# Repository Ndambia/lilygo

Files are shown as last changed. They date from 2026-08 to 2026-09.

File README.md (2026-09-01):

# LilyGo IoT Multi-Function PCB

A custom 4-layer KiCad PCB design integrating an ESP32 Wi-Fi/Bluetooth microcontroller with a SIM7600G-H 4G LTE Cat-4 cellular module, comprehensive power management, GPS tracking, GPRS connectivity, USB-C charging, LiPo battery management, environmental sensing, and USB-to-UART programming support.

---

## Table of Contents

- [Overview](#overview)
- [PCB Preview](#pcb-preview)
- [Schematic Overview](#schematic-overview)
- [Key Features](#key-features)
- [System Architecture](#system-architecture)
- [Schematic Sheets](#schematic-sheets)
- [Bill of Materials Summary](#bill-of-materials-summary)
- [Power System](#power-system)
- [Connectivity](#connectivity)
- [PCB Stackup & Design Rules](#pcb-stackup--design-rules)
- [Gerber & Manufacturing Files](#gerber--manufacturing-files)
- [Custom Libraries](#custom-libraries)
- [Datasheets](#datasheets)
- [Repository Structure](#repository-structure)
- [Getting Started](#getting-started)

---

## Overview

This project is a compact, feature-rich IoT development board built around the **ESP32-WROOM-32** and the **SIM7600G-H R2** 4G LTE module. It is designed for applications requiring cellular connectivity (4G/GPRS), GPS positioning, local Wi-Fi/Bluetooth, environmental sensing, and flexible power management from USB-C or a LiPo battery.

The board is designed in **KiCad** and targets JLCPCB / LCSC manufacturing and assembly (full BOM with LCSC part numbers included).

---

## PCB Preview

### Front Side (3D Render)

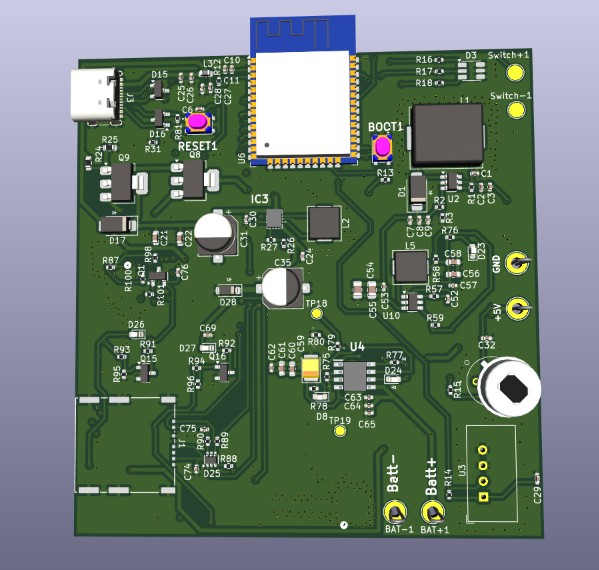
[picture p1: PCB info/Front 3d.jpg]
Front 3D Render


### Back Side (3D Render)

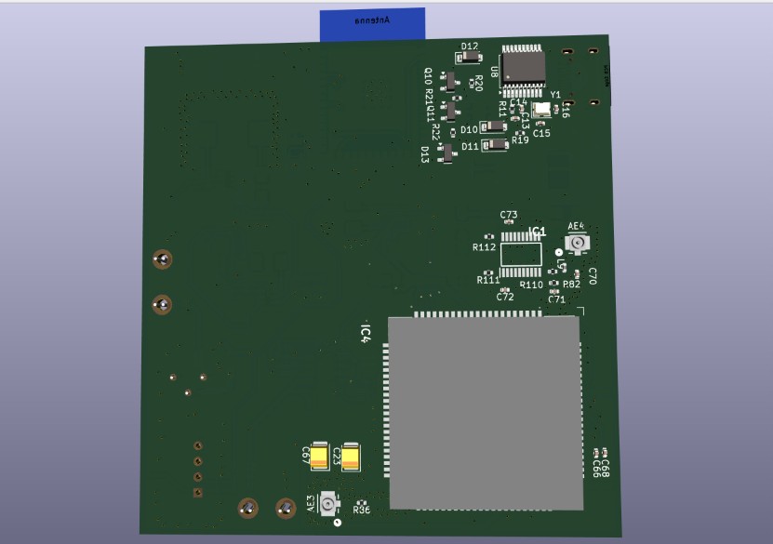
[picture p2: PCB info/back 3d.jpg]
Back 3D Render


### PCB Layout (Top View)

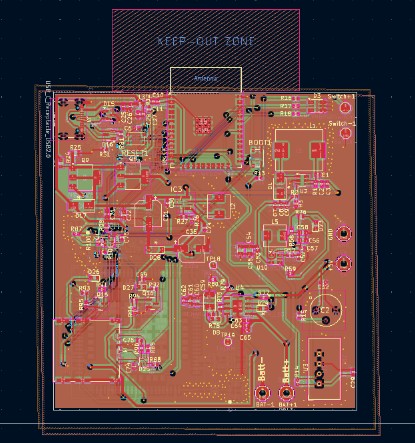
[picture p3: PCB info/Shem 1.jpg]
PCB Layout


---

## Schematic Overview

The full schematic (all sheets combined) is available as:

- 📄 [`PCB info/schematic.pdf`](PCB%20info/schematic.pdf) — Full combined schematic (all sheets)

Individual sheet PDFs:

| Sheet | Description | PDF |
|---|---|---|
| Root | Top-level schematic, ESP32, USB-UART, interfaces | *(see full schematic)* |
| BUCK\_CONVERTER\_3V3\_2A | 3.3 V / 2 A step-down (TPS56339DDCR) | [`schematic-BUCK_CONVERTER_3V3_2A_TPS56339DDCR.pdf`](PCB%20info/schematic-BUCK_CONVERTER_3V3_2A_TPS56339DDCR.pdf) |
| LIPO\_BAT\_CHARGER\_TP4056 | LiPo charger and protection circuit | [`schematic-LIPO_BAT_CHARGER_TP4056.pdf`](PCB%20info/schematic-LIPO_BAT_CHARGER_TP4056.pdf) |
| MT3608\_5V\_BOOST\_CONVERTOR | 5 V boost converter (MT3608) | [`schematic-MT3608_5V_BOOST_CONVERTOR.pdf`](PCB%20info/schematic-MT3608_5V_BOOST_CONVERTOR.pdf) |
| POWER\_PATH\_SELECTOR | Automatic USB/Battery power path switching | [`schematic-POWER_PATH_SELECTOR.pdf`](PCB%20info/schematic-POWER_PATH_SELECTOR.pdf) |
| SIM808\_GPRS\_GPS\_MODULE | SIM7600G-H R2 4G/GPS module and support circuitry | [`schematic-SIM808_GPRS_GPS_MODULE.pdf`](PCB%20info/schematic-SIM808_GPRS_GPS_MODULE.pdf) |

---

## Key Features

| Feature | Details |
|---|---|
| **MCU** | ESP32-WROOM-32D (Wi-Fi 802.11 b/g/n + Bluetooth 4.2 / BLE) |
| **Cellular** | SIM7600G-H R2 — 4G LTE Cat-4 / 3G / 2G, global bands |
| **GPS / GNSS** | Integrated via SIM7600G-H R2 (GPS + GLONASS) |
| **USB Interface** | USB-C receptacle (GCT USB4105), USB 2.0 |
| **USB-to-UART** | CH340T (SSOP-20) for ESP32 programming |
| **LiPo Charging** | TP4056 — up to 1 A charge rate, with protection |
| **3.3 V Rail** | TPS56339DDCR buck converter, 2 A output |
| **5 V Boost** | MT3608 step-up converter for 5 V peripherals |
| **Buck-Boost** | TPS630250RNCR — efficient intermediate rail |
| **Power Path** | Automatic USB / battery selector (NCE6005AR P-FETs) |
| **Environmental Sensor** | AM2302 (DHT22) — Temperature & Humidity |
| **PIR Sensor** | AS312 passive infrared motion detector |
| **SIM Card Slot** | GCT SIM7155-6-1-14-A nano/micro SIM connector |
| **GPS Antenna** | U.FL / IPEX connector (GT-RF1125A-01G) |
| **GPRS Antenna** | U.FL / IPEX connector (GT-RF1125A-01G) |
| **Level Shifting** | RS0108YQ20 8-channel bidirectional level shifter |
| **ESD Protection** | SP0502BAHT (USB lines), ESD0504F (multi-line) |
| **Reset / Boot** | Dedicated tactile push buttons (SKRPACE010) |
| **Status LEDs** | Power, Charging, Network status, RGB indicator |
| **Crystal** | 12 MHz SMD crystal (Y1) for CH340T |
| **PCB Layers** | 4-layer stackup (F.Cu / In1.Cu / In2.Cu / B.Cu) |
| **Board outline** | Edge cuts defined; antenna keep-out zone present |

---

## System Architecture

```
                          ┌──────────────────────────────────────────┐
                          │              USB-C (J3)                  │
                          │         GCT USB4105-GF-A                 │
                          └───────────────┬──────────────────────────┘
                                          │ VBUS (5V)
                          ┌───────────────▼──────────────────────────┐
                          │       Power Path Selector                │
                          │  NCE6005AR P-FET switches (Q8, Q9)       │
                          │  Auto USB / LiPo selection               │
                          └────────┬──────────────┬──────────────────┘
                                   │              │
                    ┌──────────────▼──┐    ┌──────▼──────────────────┐
                    │  TP4056 LiPo    │    │   MT3608 Boost (U2)     │
                    │  Charger (U4)   │    │   VBAT → 5 V            │
                    └──────────────┬──┘    └──────┬──────────────────┘
                                   │ VBAT         │ 5V rail
                    ┌──────────────▼──────────────▼──────────────────┐
                    │           TPS56339DDCR Buck (U10)              │
                    │              → 3.3 V / 2 A                     │
                    └──────────────┬──────────────────────────────────┘
                                   │ 3.3 V
                    ┌──────────────▼──────────────────────────────────┐
                    │         ESP32-WROOM-32D (U6)                   │
                    │    Wi-Fi / BLE / GPIO / UART / SPI / I2C       │
                    └──────┬──────────────┬──────────────────────────┘
                           │ UART         │ I2C / GPIO
          ┌────────────────▼──┐    ┌──────▼────────────────────────────┐
          │   CH340T (U8)     │    │   RS0108YQ20 Level Shifter (IC1)  │
          │   USB-UART Bridge │    │   3.3V ↔ 5V level translation     │
          └────────────────┬──┘    └──────┬────────────────────────────┘
                           │              │
                     USB-C (J3)    ┌──────▼──────────────────────────────┐
                  (programming)    │     SIM7600G-H R2 (IC4)             │
                                   │  4G LTE / 3G / 2G / GPS / GNSS     │
                                   │  GPS Antenna (AE4) + GPRS (AE3)    │
                                   │  SIM Card (J1 — SIM7155)           │
                                   └─────────────────────────────────────┘
                                   
          ┌────────────────────┐   ┌──────────────────┐
          │  AM2302 Sensor     │   │  AS312 PIR (IC2)  │
          │  Temp + Humidity   │   │  Motion Detection │
          └────────────────────┘   └──────────────────┘
```

---

## Schematic Sheets

The schematic is organized into hierarchical sheets:

### 1. Root Sheet
Top-level sheet containing:
- ESP32-WROOM-32D microcontroller and decoupling
- CH340T USB-to-UART bridge with 12 MHz crystal
- RS0108YQ20 bidirectional level shifter
- Reset and Boot buttons
- AM2302 temperature/humidity sensor
- AS312 PIR motion sensor
- Status LEDs (Power, Charging, Network, RGB)
- ESD protection diodes

### 2. BUCK_CONVERTER_3V3_2A_TPS56339DDCR
- Texas Instruments TPS56339DDCR synchronous buck regulator
- Input: up to ~5.5 V (battery or boosted USB)
- Output: 3.3 V @ 2 A for ESP32 and logic
- Teardrop-optimized copper pours

### 3. LIPO_BAT_CHARGER_TP4056
- TP4056 single-cell LiPo/Li-Ion charger IC
- Charge current configurable via R-prog resistor
- Charging indicator LED (D8 — Red) and Done indicator (D24 — Green)
- SS54 Schottky diode for reverse protection
- 4.2 V Zener clamp (D28) for overvoltage protection
- Large bulk capacitors (220 µF electrolytic on BAT+ rail)

### 4. MT3608_5V_BOOST_CONVERTOR
- MT3608 2 A boost converter (U2, SOT-23-6)
- Boosts VBAT (~3.7 V) to 5 V for USB and module power
- Inductor: 1 µH power bead (L2)
- SS54 freewheeling diode

### 5. POWER_PATH_SELECTOR
- Automatic switchover between USB VBUS and LiPo battery
- P-channel MOSFETs NCE6005AR (Q8, Q9) in back-to-back configuration
- Prevents battery discharge when USB is connected
- Handles reverse current blocking

### 6. SIM808_GPRS_GPS_MODULE (SIM7600G-H R2)
- SIM7600G-H R2 global-band 4G LTE Cat-4 module (IC4)
- GPS/GLONASS integrated receiver
- GPRS antenna connector AE3 (U.FL / IPEX)
- GPS antenna connector AE4 (U.FL / IPEX)
- SIM card connector J1 (GCT SIM7155-6-1-14-A)
- TPS630250RNCR buck-boost for module power rail
- Large 220 µF tantalum bulk capacitors for surge current

---

## Bill of Materials Summary

> Full BOM: [`Manufacturing files/BOM.csv`](Manufacturing%20files/BOM.csv)  
> Schematic netlist CSV: [`schematic.csv`](schematic.csv)

### ICs & Modules

| Ref | Part | Description |
|---|---|---|
| U6 | ESP32-WROOM-32D-N4 | Wi-Fi + BT MCU module |
| IC4 | SIM7600G-H R2 | 4G LTE / GPS module |
| U4 | TP4056 | LiPo battery charger |
| U10 | TPS56339DDCR | 3.3 V / 2 A buck regulator |
| U2 | MT3608 | 5 V boost converter |
| IC3 | TPS630250RNCR | Buck-boost regulator |
| IC1 | RS0108YQ20 | 8-ch bidirectional level shifter |
| IC2 | AS312 | PIR motion sensor |
| U8 | CH340T (SSOP-20) | USB-to-UART bridge |
| U3 | AM2302 | DHT22 temperature & humidity sensor |

### Connectors

| Ref | Part | Description |
|---|---|---|
| J3 | USB4105-GF-A | USB-C receptacle (USB 2.0) |
| J1 | SIM7155-6-1-14-A | SIM card connector |
| AE3 | GT-RF1125A-01G | GPRS / LTE antenna (U.FL) |
| AE4 | GT-RF1125A-01G | GPS antenna (U.FL) |

### Semiconductors & Passives (Key)

| Ref | Value/Part | Description |
|---|---|---|
| Q8, Q9 | NCE6005AR | P-channel power MOSFETs (power path) |
| Q15, Q16 | SI2302 | N-channel MOSFETs |
| Q10, Q11 | MMBT3904 | NPN signal transistors |
| Q1 | BC817 | NPN transistor |
| D1, D17 | SS54 | 5 A Schottky diodes |
| D10–D12 | B5819W | 1 A Schottky diodes |
| D13 | BAT54C | Dual Schottky (SOT-23) |
| D28 | BZT52C4V3 | 4.3 V Zener clamp |
| D3 | SMLVN6RGBFU1 | RGB LED |
| D15, D16 | SP0502BAHT | USB ESD protection |
| D25 | ESD0504F | Multi-line ESD protection |
| Y1 | 12 MHz | SMD crystal (2520 4-pin) for CH340T |
| L1 | 22 µH | Chilisin power inductor (buck) |
| L2 | 1 µH | Chilisin power inductor (boost) |
| L5 | 4.7 µH | Chilisin power inductor (buck-boost) |
| C31, C35 | 220 µF | Electrolytic bulk caps |
| C23, C67 | 220 µF | Tantalum bulk caps (cellular surge) |

Total unique component lines in BOM: **~82 line items**

---

## Power System

```
USB-C VBUS (5 V)
     │
     ├──► Power Path Selector (NCE6005AR)
     │         │
     │    ┌────┴──────────────────────────────────────────┐
     │    │ When USB present: powers system, charges LiPo │
     │    │ When no USB: LiPo powers system               │
     │    └────────────────────────────────────────────────┘
     │
     ├──► TP4056 LiPo Charger ──► LiPo Battery (BAT+ / BAT-)
     │
     └──► MT3608 Boost ──► 5 V internal rail
               │
               └──► TPS56339DDCR Buck ──► 3.3 V (ESP32, logic, peripherals)
                         │
                         └──► TPS630250RNCR Buck-Boost ──► SIM7600G-H power rail
```

| Rail | Regulator | Max Current | Load |
|---|---|---|---|
| 5 V boost | MT3608 | 2 A | Module VCC, USB |
| 3.3 V | TPS56339DDCR | 2 A | ESP32, logic ICs, sensors |
| Module VCC | TPS630250RNCR | — | SIM7600G-H R2 |
| VBAT | TP4056 output | 1 A charge | LiPo cell |

---

## Connectivity

| Interface | Notes |
|---|---|
| **4G LTE / GPRS** | SIM7600G-H R2, global bands, SMA/U.FL antenna |
| **GPS / GNSS** | Integrated in SIM7600G-H R2, dedicated U.FL antenna |
| **Wi-Fi** | ESP32 802.11 b/g/n (PCB trace antenna on module) |
| **Bluetooth** | ESP32 BT Classic 4.2 + BLE |
| **USB** | USB-C, USB 2.0, via CH340T UART bridge for programming |
| **Temperature/Humidity** | AM2302 (DHT22) single-wire protocol |
| **PIR Motion** | AS312 digital output |
| **SIM** | Nano/micro SIM via GCT connector |

---

## PCB Stackup & Design Rules

| Parameter | Value |
|---|---|
| **Layers** | 4 (F.Cu, In1.Cu, In2.Cu, B.Cu) |
| **Min track width** | 0.2 mm |
| **Min clearance** | 0.129 mm |
| **Min via diameter** | 0.6 mm |
| **Via drill** | 0.3 mm |
| **Min annular ring** | 0.15 mm |
| **Min hole-to-hole** | 0.25 mm |
| **Min copper-edge clearance** | 0.5 mm |
| **Solder mask clearance** | 0.005 mm |
| **Track widths used** | 0.19, 0.25, 0.3, 0.6 mm |
| **Teardrops** | Enabled on PTH pads, SMD pads, and vias |

> ⚠️ **Antenna Keep-Out Zone**: A copper-free keep-out zone is defined above the ESP32 module and near the cellular/GPS antenna connectors. Do not route traces or place copper fills in this area.

---

## Gerber & Manufacturing Files

### Gerber Files (`Gerber/`)

| File | Layer |
|---|---|
| `schematic-F_Cu.gbr` | Front copper |
| `schematic-B_Cu.gbr` | Back copper |
| `schematic-In1_Cu.gbr` | Inner layer 1 |
| `schematic-In2_Cu.gbr` | Inner layer 2 |
| `schematic-F_Mask.gbr` | Front solder mask |
| `schematic-B_Mask.gbr` | Back solder mask |
| `schematic-F_Paste.gbr` | Front solder paste |
| `schematic-B_Paste.gbr` | Back solder paste |
| `schematic-F_Silkscreen.gbr` | Front silkscreen |
| `schematic-B_Silkscreen.gbr` | Back silkscreen |
| `schematic-Edge_Cuts.gbr` | Board outline |
| `schematic-PTH.drl` | Plated through-hole drill file |
| `schematic-NPTH.drl` | Non-plated through-hole drill file |
| `schematic-job.gbrjob` | Gerber job file |

> 📦 Pre-zipped package: [`Gerber.zip`](Gerber.zip)

### Manufacturing Files (`Manufacturing files/`)

| File | Description |
|---|---|
| [`BOM.csv`](Manufacturing%20files/BOM.csv) | Full BOM with LCSC part numbers for JLCPCB SMT |
| [`Gerber.zip`](Manufacturing%20files/Gerber.zip) | Gerber archive for board fabrication |
| `placement/schematic-all-pos.csv` | Component placement / pick-and-place file |

---

## Custom Libraries (`lib/`)

Custom KiCad footprint and symbol libraries used in this project:

| Library | Part |
|---|---|
| `LIB_AM2302` | DHT22 / AM2302 temperature & humidity sensor |
| `LIB_AS312` | AS312 PIR motion sensor |
| `LIB_AXP2101` | AXP2101 power management IC |
| `LIB_RS0108YQ20` | RS0108YQ20 level shifter |
| `LIB_SIM7080G` | SIM7080G NB-IoT / Cat-M module |
| `LIB_SIM7600G-H_R2` | SIM7600G-H R2 4G module |
| `LIB_SKRPACE010` | SKRPACE010 tactile switch |
| `LIB_TP4056` | TP4056 LiPo charger |
| `LIB_TPS630250RNCR` | TPS630250RNCR buck-boost regulator |
| `Antenna conector` | U.FL / IPEX antenna connector |
| `SIM7155_6_1_14_A` | GCT SIM card connector |

---

## Datasheets (`Datasheet/`)

| Document | Description |
|---|---|
| [`AXP2101.pdf`](Datasheet/AXP2101.pdf) | AXP2101 PMIC datasheet |
| [`T-SIM7080G_Schematic.pdf`](Datasheet/T-SIM7080G_Schematic.pdf) | LilyGo T-SIM7080G reference schematic |
| [`TDM-2202_TDM-2205_ESP32-X7600X_schematic.pdf`](Datasheet/TDM-2202_TDM-2205_ESP32-X7600X_schematic.pdf) | ESP32 + SIM7600 reference design |
| [`sim7600 schematic.pdf`](Datasheet/sim7600%20schematic.pdf) | SIM7600 series module schematic reference |
| [`tps630250.pdf`](Datasheet/tps630250.pdf) | TPS630250 buck-boost regulator datasheet |

---

## Repository Structure

```
lilygo/
├── README.md                    ← This file
├── schematic.csv                ← Component netlist export
├── Gerber.zip                   ← Fabrication-ready Gerber archive
│
├── PCB info/                    ← Visual references
│   ├── Front 3d.jpg             ← 3D render — front
│   ├── back 3d.jpg              ← 3D render — back
│   ├── Shem 1.jpg               ← PCB layout screenshot
│   ├── schematic.pdf            ← Full combined schematic PDF
│   ├── schematic-BUCK_CONVERTER_3V3_2A_TPS56339DDCR.pdf
│   ├── schematic-LIPO_BAT_CHARGER_TP4056.pdf
│   ├── schematic-MT3608_5V_BOOST_CONVERTOR.pdf
│   ├── schematic-POWER_PATH_SELECTOR.pdf
│   └── schematic-SIM808_GPRS_GPS_MODULE.pdf
│
├── schematic/                   ← KiCad project files
│   ├── schematic.kicad_pro      ← KiCad project settings
│   ├── schematic.kicad_pcb      ← PCB layout file
│   ├── schematic.kicad_sch      ← Root schematic sheet
│   ├── BUCK_CONVERTER_3V3_2A_TPS56339DDCR.kicad_sch
│   ├── LIPO_BAT_CHARGER_TP4056.kicad_sch
│   ├── MT3608_5V_BOOST_CONVERTOR.kicad_sch
│   ├── POWER_PATH_SELECTOR.kicad_sch
│   └── SIM808_GPRS_GPSS_MODULE.kicad_sch
│
├── Gerber/                      ← Individual Gerber layer files
├── Manufacturing files/         ← JLCPCB production package
│   ├── BOM.csv                  ← BOM with LCSC part numbers
│   ├── Gerber.zip
│   └── placement/
│       └── schematic-all-pos.csv ← Pick-and-place file
│
├── lib/                         ← Custom KiCad libraries
│   ├── LIB_AM2302/
│   ├── LIB_AS312/
│   ├── LIB_SIM7600G-H_R2/
│   ├── LIB_TP4056/
│   ├── LIB_TPS630250RNCR/
│   └── ...
│
├── Datasheet/                   ← Reference datasheets
└── placement/                   ← Placement CSV (root-level copy)
```

---

## Getting Started

### Prerequisites

- [KiCad 7 or later](https://www.kicad.org/download/) (project was created with KiCad 7/8)
- LCSC / JLCPCB account for ordering

### Opening the Project

1. Clone or download this repository.
2. Open KiCad and select **File → Open Project**.
3. Navigate to `schematic/schematic.kicad_pro` and open it.
4. The schematic editor and PCB layout editor will be available from the KiCad project manager.

> **Note**: Ensure the `lib/` directory is accessible to KiCad for custom footprints and symbols. If prompted, add `lib/` as a project-level footprint library path in **Preferences → Manage Footprint Libraries**.

### Ordering the PCB (JLCPCB)

1. Upload [`Gerber.zip`](Gerber.zip) (or [`Manufacturing files/Gerber.zip`](Manufacturing%20files/Gerber.zip)) to [JLCPCB](https://jlcpcb.com).
2. Select **4-layer** stackup.
3. For SMT assembly, also upload:
   - [`Manufacturing files/BOM.csv`](Manufacturing%20files/BOM.csv)
   - [`Manufacturing files/placement/schematic-all-pos.csv`](Manufacturing%20files/placement/schematic-all-pos.csv)
4. Review component availability and substitutions as needed.

### Programming the ESP32

The board includes an on-board CH340T USB-to-UART bridge. To program:

1. Connect a USB-C cable to **J3**.
2. The CH340T will enumerate as a serial COM port.
3. Use the Arduino IDE, ESP-IDF, or PlatformIO targeting **ESP32-WROOM-32**.
4. Hold **BOOT** button while pressing **RESET** to enter download mode if needed.

---

*PCB designed in KiCad. Manufactured via JLCPCB. All LCSC part numbers included in BOM for one-stop sourcing.*

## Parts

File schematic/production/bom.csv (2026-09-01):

Designator | Footprint | Quantity | Value | LCSC Part #
+5V | TestPoint_Loop_D2.50mm_Drill1.85mm | 1 | 5v
AE3 | CONN_2337019-1_TEC | 1 | GPRS_ANTENNA | BWU.FL-IPEX1
AE4 | CONN_2337019-1_TEC | 1 | GPS_ANTENNA | BWU.FL-IPEX1
BAT+1 | TestPoint_Loop_D2.50mm_Drill1.85mm | 1 | BAT+
BAT-1 | TestPoint_Loop_D2.50mm_Drill1.85mm | 1 | BAT-
BOOT1, RESET1 | SMT_4.2X3.2_ | 2 | SW_Push
C1, C2, C30, C64, C65, C8, C9 | 0402 | 7 | 22u
C10, C68 | 0402 | 2 | 10u
C11, C6 | 0402 | 2 | 0.1u
C13 | 0402 | 1 | 22uF
C14, C52 | 0402 | 2 | 100nF
C15, C16 | 0402 | 2 | 22pF
C21 | 0603 | 1 | 4.7u
C22, C60 | 0603 | 2 | 10u
C23, C67 | CP_EIA-3528-21_Kemet-B | 2 | 220u | TLJB227M006R0500
C24, C27, C29, C3, C32, C62, C63, C66, C7, C72, C73, C74, C76 | 0402 | 13 | 100n
C25, C28 | 0402 | 2 | 4.7u
C26 | 0402 | 1 | 10n
C31, C35 | CP_Elec_6.3x5.4 | 2 | 220u | RVT1A221M0605
C53, C57 | 0402 | 2 | 100nF_65V
C54, C55 | 0805 | 2 | 10uF
C56, C58 | 0603 | 2 | 22uF
C59 | CP_EIA-3528-21_Kemet-B | 1 | 47u | TAJB476K010RNJ
C61 | 0603 | 1 | 100n
C69, C71 | 0402 | 2 | 33p
C70, C75 | 0402 | 2 | 22p
D1, D17 | D_SMA | 2 | SS54
D10, D11, D12 | D_SOD-123 | 3 | B5819W
D13 | SOT-23 | 1 | BAT54C
D15, D16 | SOT-23 | 2 | SP0502BAHT
D23 | 0603 | 1 | PWR
D24 | 0603 | 1 | DONE_GRN_LED
D25 | SOT-363_SC-70-6 | 1 | ESD0504F | ESD0504F
D26 | 0603 | 1 | LED_net
D27 | 0603 | 1 | LED_status
D28 | D_SOD-123 | 1 | 4.2v Zener
D3 | LED_ROHM_SMLVN6 | 1 | SMLVN6RGB
D8 | 0603 | 1 | CHARGING_RED_LED
GND | TestPoint_Loop_D2.50mm_Drill1.85mm | 1 | GND
IC1 | SOP65P640X120-20N | 1 | RS0108YQ20
IC2 | AS312 | 1 | AS312
IC3 | TPS630250RNCR | 1 | TPS630250RNCR
IC4 | SIM7600GHR2 | 1 | SIM7600G-H_R2
J1 | SIM7155-6-1-14-A_GCT | 1 | SIM7155-6-1-14-A
J3 | USB_C_Receptacle_GCT_USB4105-xx-A_16P_TopMnt_Horizontal | 1 | USB_C_Receptacle_USB2.0
L1 | L_Chilisin_BMRG00101030 | 1 | 22uH | CYA1040-22UH
L2 | L_Chilisin_BMRx00050512-B | 1 | 1uH | YSPI0530S-1R0M
L3 | 0603 | 1 | 2A_bead
L5 | L_Chilisin_BMRx00050512-B | 1 | 4.7uH | YSPI0530S-4R7M
L9 | 0402 | 1 | 47nH
Q1 | SOT-23 | 1 | BC817
Q10, Q11 | SOT-23 | 2 | MMBT3904
Q15, Q16 | SOT-23 | 2 | SI2302
Q8, Q9 | SOT-223-3_TabPin2 | 2 | NCE6005AR
R1, R11, R110, R12, R13, R19, R20, R21, R59, R95, R96 | 0402 | 11 | 10K
R100, R101, R14, R87, R98 | 0402 | 5 | 4.7k
R111, R112 | 0402 | 2 | 47k
R15, R16, R17, R18, R75, R76, R77, R78, R93, R94 | 0402 | 10 | 1k
R2 | 0402 | 1 | 120K
R22 | 0402 | 1 | 220R
R24 | 0603 | 1 | 1K
R25 | 0603 | 1 | 10K
R26 | 0402 | 1 | 720K
R27 | 0402 | 1 | 180K
R3 | 0402 | 1 | 16K
R31, R81 | 0402 | 2 | 5.1K
R57 | 0402 | 1 | 30R
R58 | 0402 | 1 | 30.9K
R79 | 0402 | 1 | 4870
R80 | 0402 | 1 | 86600
R82 | 0402 | 1 | 47R
R86 | 0402 | 1 | 0R
R88, R89, R90 | 0402 | 3 | 22R
R91, R92 | 0402 | 2 | 390R
SWITCH+1 | TestPoint_Pad_D2.5mm | 1 | Switch+
SWITCH-1 | TestPoint_Pad_D2.5mm | 1 | Switch-
TP18 | TestPoint_Pad_D1.5mm | 1 | THERM+
TP19 | TestPoint_Pad_D1.5mm | 1 | THERM-
U10 | SOT-23-6 | 1 | TPS56339DDC
U2 | SOT-23-6 | 1 | MT3608
U3 | ASAIR_AM2302_P2.54mm_Vertical | 1 | AM2302
U4 | SOIC127P600X175-9N | 1 | TP4056
U6 | ESP32-WROOM-32 | 1 | ESP32-WROOM-32
U8 | SSOP-20_5.3x7.2mm_P0.65mm | 1 | CH340T(SSOP20W)
Y1 | Crystal_SMD_2520-4Pin_2.5x2.0mm | 1 | 12MHz

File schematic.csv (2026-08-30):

Comment | Designator | Footprint | Quantity
4.7u | C21 | C_0603_1608Metric | 1
16K | R3 | R_0402_1005Metric | 1
SP0502BAHT | D15,D16 | SOT-23 | 2
LED_net | D26 | LED_0603_1608Metric | 1
SW_Push | RESET1,BOOT1 | SMT_4.2X3.2_ | 2
1K | R94,R78,R76,R77,R93,R75 | R_0402_1005Metric | 6
33p | C69,C71 | C_0402_1005Metric | 2
10n | C26 | C_0402_1005Metric_Pad0.74x0.62mm_HandSolder | 1
1K | R24 | R_0603_1608Metric | 1
100n | C24,C74,C76,C3,C62,C63,C7,C66,C72,C73 | C_0402_1005Metric | 10
22R | R89,R90,R88 | R_0402_1005Metric | 3
SIM7155-6-1-14-A | J1 | SIM7155-6-1-14-A_GCT | 1
4.7u | C28,C25 | C_0402_1005Metric_Pad0.74x0.62mm_HandSolder | 2
0.1u | C6,C11 | C_0402_1005Metric | 2
MT3608 | U2 | SOT-23-6 | 1
22u | C65,C9,C8,C1,C64,C2,C30 | C_0402_1005Metric | 7
PWR | D23 | LED_0603_1608Metric | 1
10K | R25 | R_0603_1608Metric | 1
2A_bead | L3 | L_0603_1608Metric | 1
30.9K | R58 | R_0402_1005Metric | 1
100nF | C52,C14 | C_0402_1005Metric | 2
4.7k | R98,R87,R14,R100,R101 | R_0402_1005Metric | 5
LED_status | D27 | LED_0603_1608Metric | 1
10K | R59,R1,R95,R96 | R_0402_1005Metric | 4
390R | R92,R91 | R_0402_1005Metric | 2
10k | R13,R12,R11,R20,R19,R21,R110 | R_0402_1005Metric | 7
1uH | L2 | L_Chilisin_BMRx00050512-B | 1
SS54 | D17,D1 | D_SMA | 2
22uF | C58,C56 | C_0603_1608Metric | 2
10u | C10,C68 | C_0402_1005Metric | 2
120K | R2 | R_0402_1005Metric | 1
10uF | C55,C54 | C_0805_2012Metric | 2
86600 | R80 | R_0402_1005Metric | 1
SMLVN6RGB | D3 | LED_ROHM_SMLVN6 | 1
100n | C61 | C_0603_1608Metric | 1
720K | R26 | R_0402_1005Metric | 1
ESD0504F | D25 | SOT-363_SC-70-6 | 1
220u | C35,C31 | CP_Elec_6.3x5.4 | 2
AS312 | IC2 | AS312 | 1
10u | C22,C60 | C_0603_1608Metric | 2
SI2302 | Q16,Q15 | SOT-23 | 2
DONE_GRN_LED | D24 | LED_0603_1608Metric | 1
100nF_65V | C53,C57 | C_0402_1005Metric | 2
NCE6005AR | Q9,Q8 | SOT-223-3_TabPin2 | 2
22p | C75,C70 | C_0402_1005Metric | 2
TPS56339DDC | U10 | SOT-23-6 | 1
100n | C32,C29,C27 | C_0402_1005Metric_Pad0.74x0.62mm_HandSolder | 3
5.1K | R31,R81 | R_0402_1005Metric | 2
22uH | L1 | L_Chilisin_BMRG00101030 | 1
47u | C59 | CP_EIA-3528-21_Kemet-B | 1
1k | R17,R18,R15,R16 | R_0402_1005Metric | 4
4870 | R79 | R_0402_1005Metric | 1
180K | R27 | R_0402_1005Metric | 1
AM2302 | U3 | ASAIR_AM2302_P2.54mm_Vertical | 1
USB_C_Receptacle_USB2.0 | J3 | USB_C_Receptacle_GCT_USB4105-xx-A_16P_TopMnt_Horizontal | 1
4.7uH | L5 | L_Chilisin_BMRx00050512-B | 1
4.2v Zener | D28 | D_SOD-123 | 1
TP4056 | U4 | SOIC127P600X175-9N | 1
30R | R57 | R_0402_1005Metric | 1
TPS630250RNCR | IC3 | TPS630250RNCR | 1
BC817 | Q1 | SOT-23 | 1
CHARGING_RED_LED | D8 | LED_0603_1608Metric | 1
ESP32-WROOM-32 | U6 | ESP32-WROOM-32 | 1
RS0108YQ20 | IC1 | SOP65P640X120-20N | 1
22pF | C15,C16 | C_0402_1005Metric | 2
BAT54C | D13 | SOT-23 | 1
47R | R82 | R_0402_1005Metric | 1
CH340T(SSOP20W) | U8 | SSOP-20_5.3x7.2mm_P0.65mm | 1
B5819W | D10,D12,D11 | D_SOD-123 | 3
MMBT3904 | Q11,Q10 | SOT-23 | 2
12MHz | Y1 | Crystal_SMD_2520-4Pin_2.5x2.0mm | 1
GPS_ANTENNA | AE4 | CONN_2337019-1_TEC | 1
220u | C23,C67 | CP_EIA-3528-21_Kemet-B | 2
47k | R112,R111 | R_0402_1005Metric | 2
47nH | L9 | L_0402_1005Metric | 1
GPRS_ANTENNA | AE3 | CONN_2337019-1_TEC | 1
0R | R86 | R_0402_1005Metric | 1
220R | R22 | R_0402_1005Metric | 1
SIM7600G-H_R2 | IC4 | SIM7600GHR2 | 1
22uF | C13 | C_0402_1005Metric | 1

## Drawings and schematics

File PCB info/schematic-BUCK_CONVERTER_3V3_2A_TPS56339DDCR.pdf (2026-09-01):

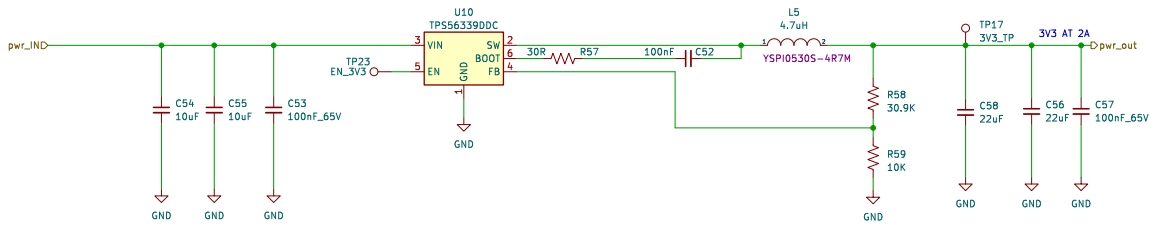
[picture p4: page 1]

1 SW 2 BOOT 6 FB 4 U10 TPS56339DDC GND

Id: 2/7 Title: File: BUCK_CONVERTER_3V3_2A_TPS56339DDCR.kicad_sch Sheet: /BUCK_CONVERTER_3V3_2A_TPS56339DDCR/

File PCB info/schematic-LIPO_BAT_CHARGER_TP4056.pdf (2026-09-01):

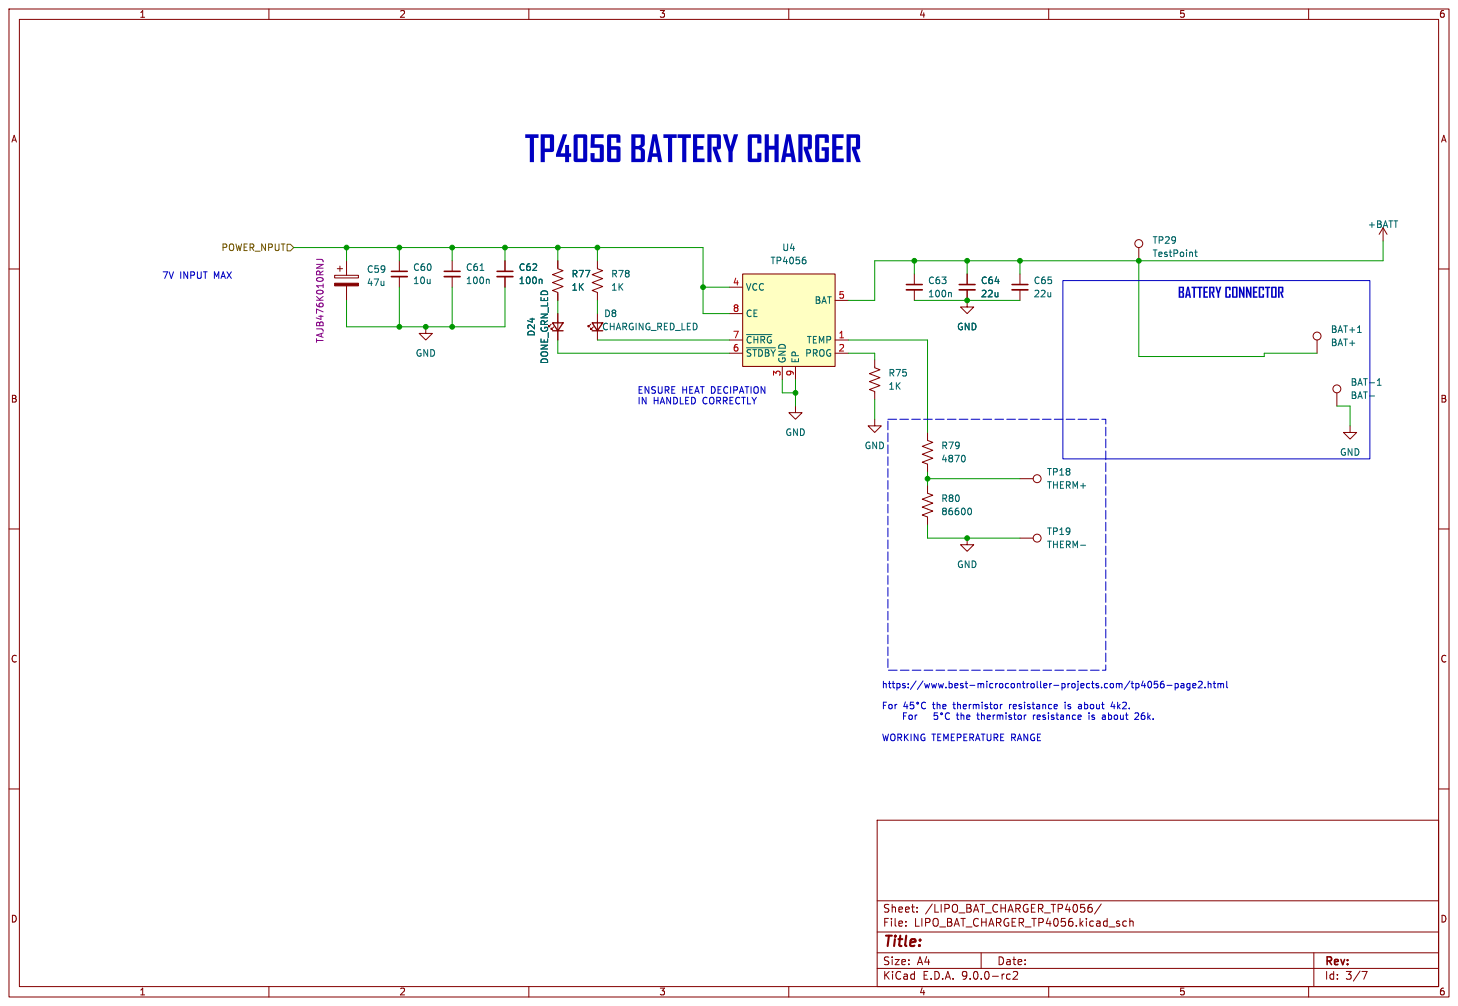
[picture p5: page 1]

BAT+1 BAT+BAT-1 BAT- GND

https://www.best-microcontroller-projects.com/tp4056-page2.html ENSURE HEAT DECIPATION

Id: 3/7 Title: File: LIPO_BAT_CHARGER_TP4056.kicad_sch Sheet: /LIPO_BAT_CHARGER_TP4056/

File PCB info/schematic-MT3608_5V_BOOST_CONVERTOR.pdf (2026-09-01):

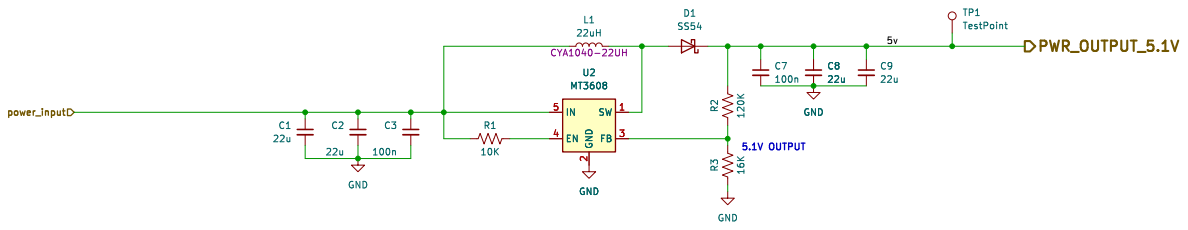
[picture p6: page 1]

Id: 6/7 Title: File: MT3608_5V_BOOST_CONVERTOR.kicad_sch Sheet: /MT3608_5V_BOOST_CONVERTOR/ C3

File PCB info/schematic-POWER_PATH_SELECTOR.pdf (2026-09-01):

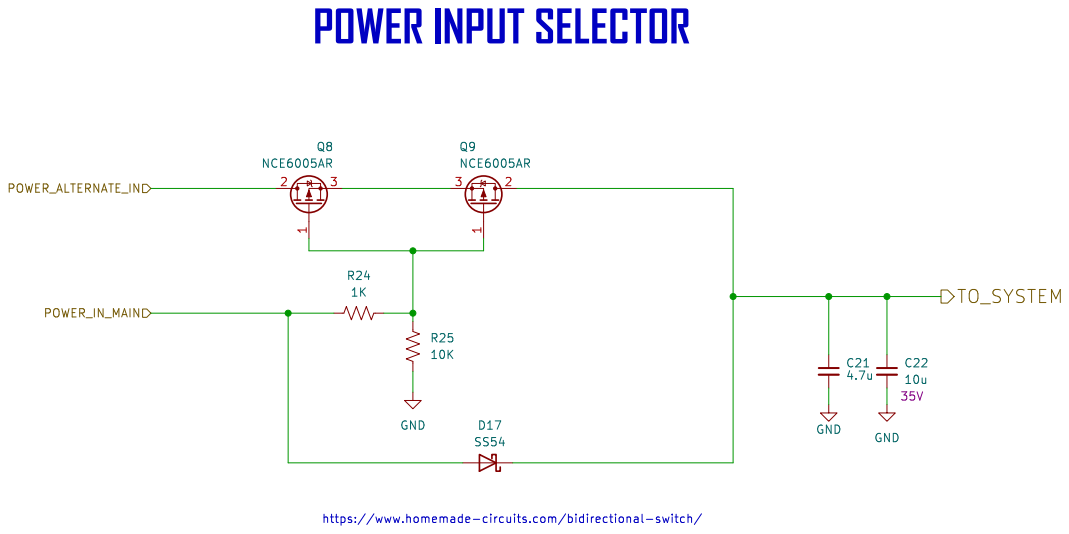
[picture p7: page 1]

Id: 5/7 Title: File: POWER_PATH_SELECTOR.kicad_sch Sheet: /POWER_PATH_SELECTOR/ GND

https://www.homemade-circuits.com/bidirectional-switch/

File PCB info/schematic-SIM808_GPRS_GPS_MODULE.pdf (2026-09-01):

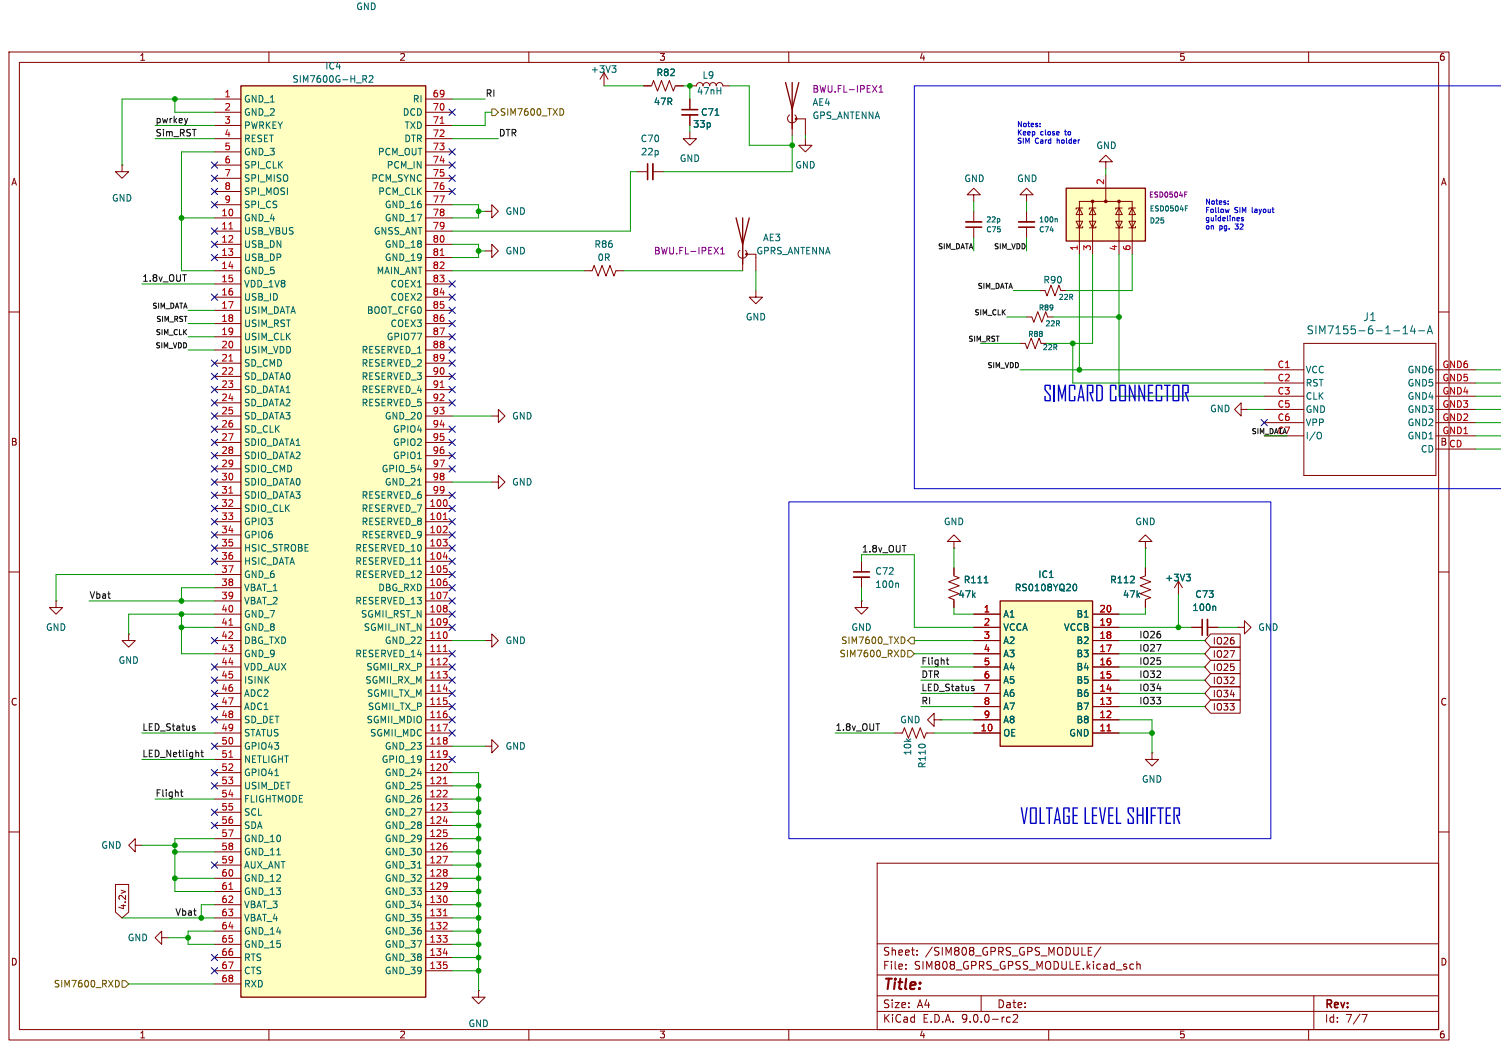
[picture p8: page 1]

STATUS LIGHT VOLTAGE LEVELSHIFTER

Notes: Keep close to SIM Card holder SIMCARD CONNECTOR

Id: 7/7 Title: File: SIM808_GPRS_GPSS_MODULE.kicad_sch Sheet: /SIM808_GPRS_GPS_MODULE/ GND

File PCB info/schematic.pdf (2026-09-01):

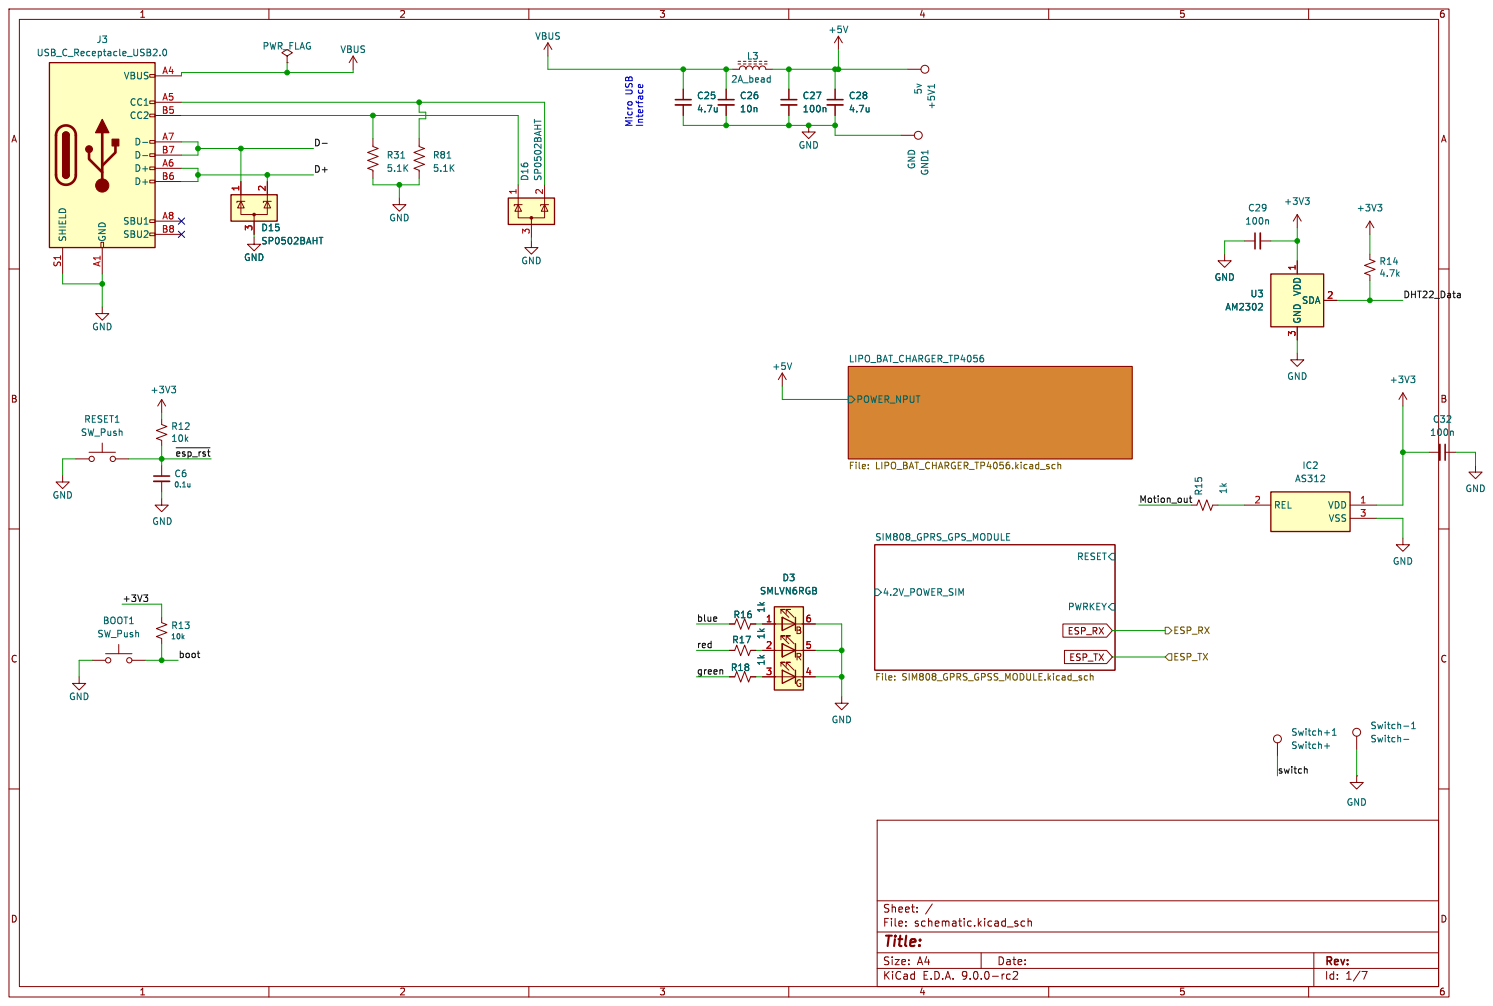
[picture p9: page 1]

3 SDA U3 2 AM2302 GND GND GND

Id: 1/7 Title: File: schematic.kicad_sch Sheet: /


1 SW 2 BOOT 6 FB 4 U10 TPS56339DDC GND

Id: 2/7 Title: File: BUCK_CONVERTER_3V3_2A_TPS56339DDCR.kicad_sch Sheet: /BUCK_CONVERTER_3V3_2A_TPS56339DDCR/


9 BAT 5 TEMP 1 PROG 2 U4 TP4056 GND

BAT+1 BAT+BAT-1 BAT- GND

https://www.best-microcontroller-projects.com/tp4056-page2.html ENSURE HEAT DECIPATION

Id: 3/7 Title: File: LIPO_BAT_CHARGER_TP4056.kicad_sch Sheet: /LIPO_BAT_CHARGER_TP4056/

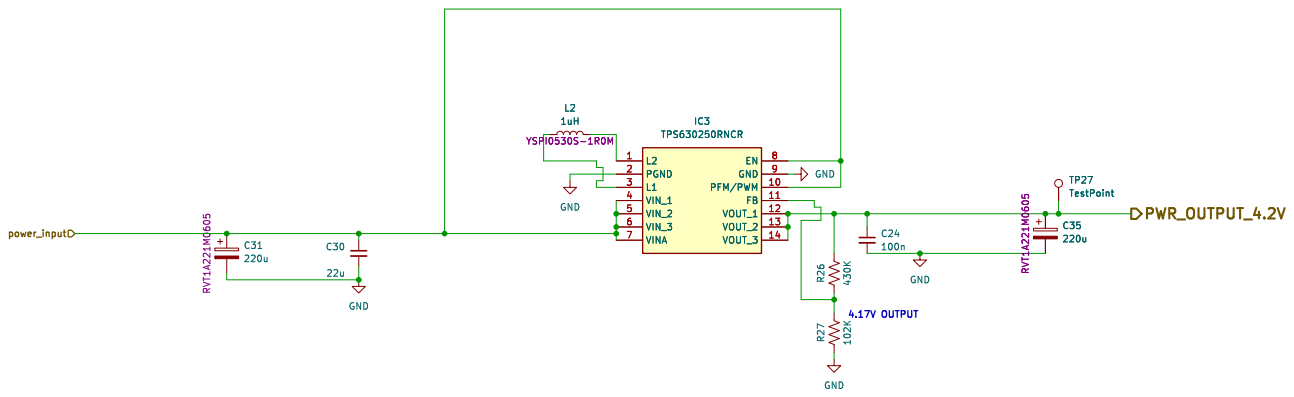
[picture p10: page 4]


Id: 5/7 Title: File: POWER_PATH_SELECTOR.kicad_sch Sheet: /POWER_PATH_SELECTOR/ GND

https://www.homemade-circuits.com/bidirectional-switch/


Id: 6/7 Title: File: MT3608_5V_BOOST_CONVERTOR.kicad_sch Sheet: /MT3608_5V_BOOST_CONVERTOR/ C3


STATUS LIGHT VOLTAGE LEVELSHIFTER

Notes: Keep close to SIM Card holder SIMCARD CONNECTOR

Id: 7/7 Title: File: SIM808_GPRS_GPSS_MODULE.kicad_sch Sheet: /SIM808_GPRS_GPS_MODULE/ GND

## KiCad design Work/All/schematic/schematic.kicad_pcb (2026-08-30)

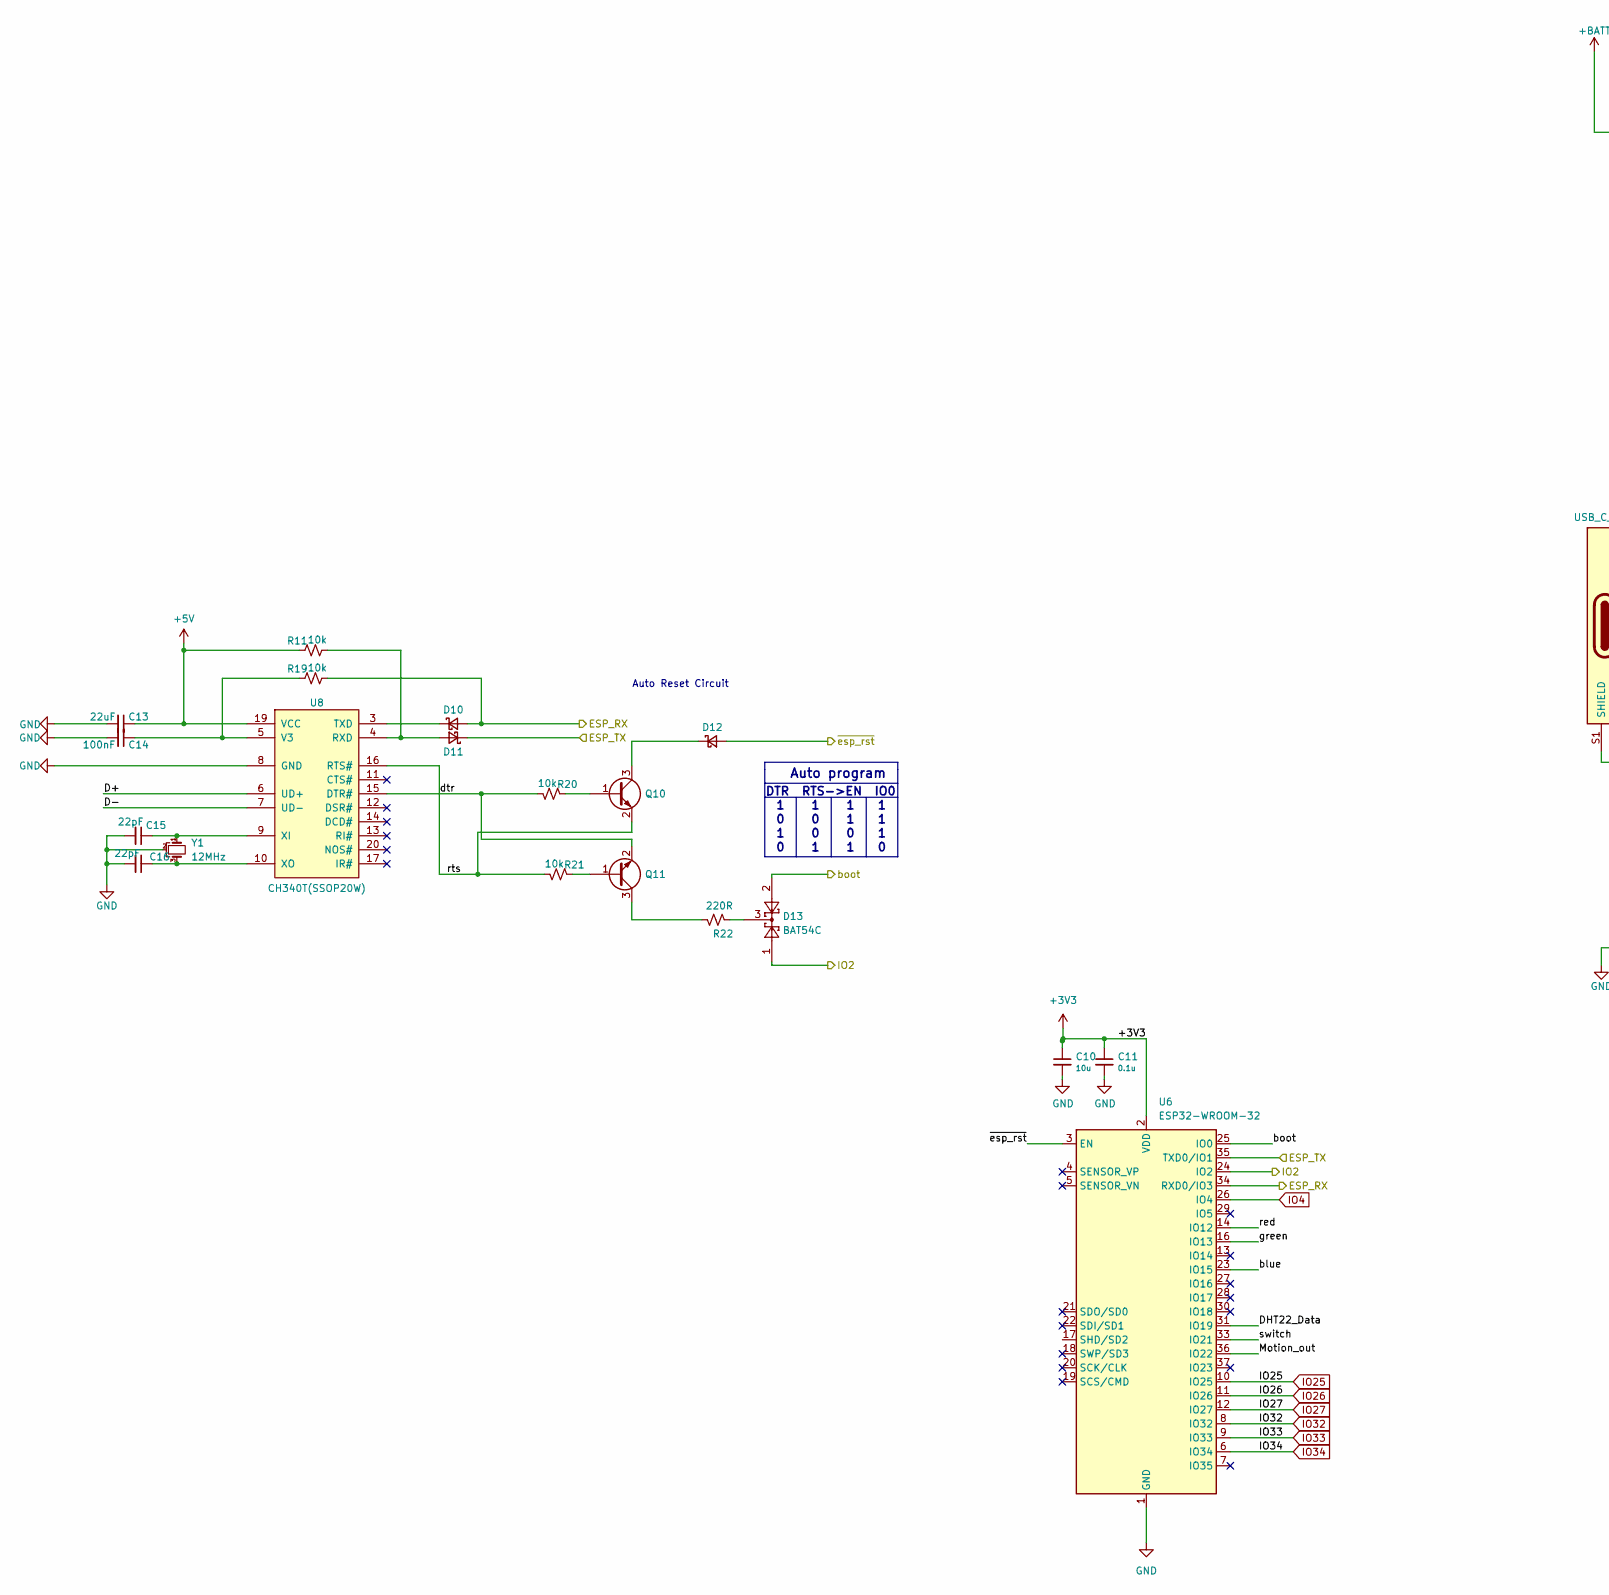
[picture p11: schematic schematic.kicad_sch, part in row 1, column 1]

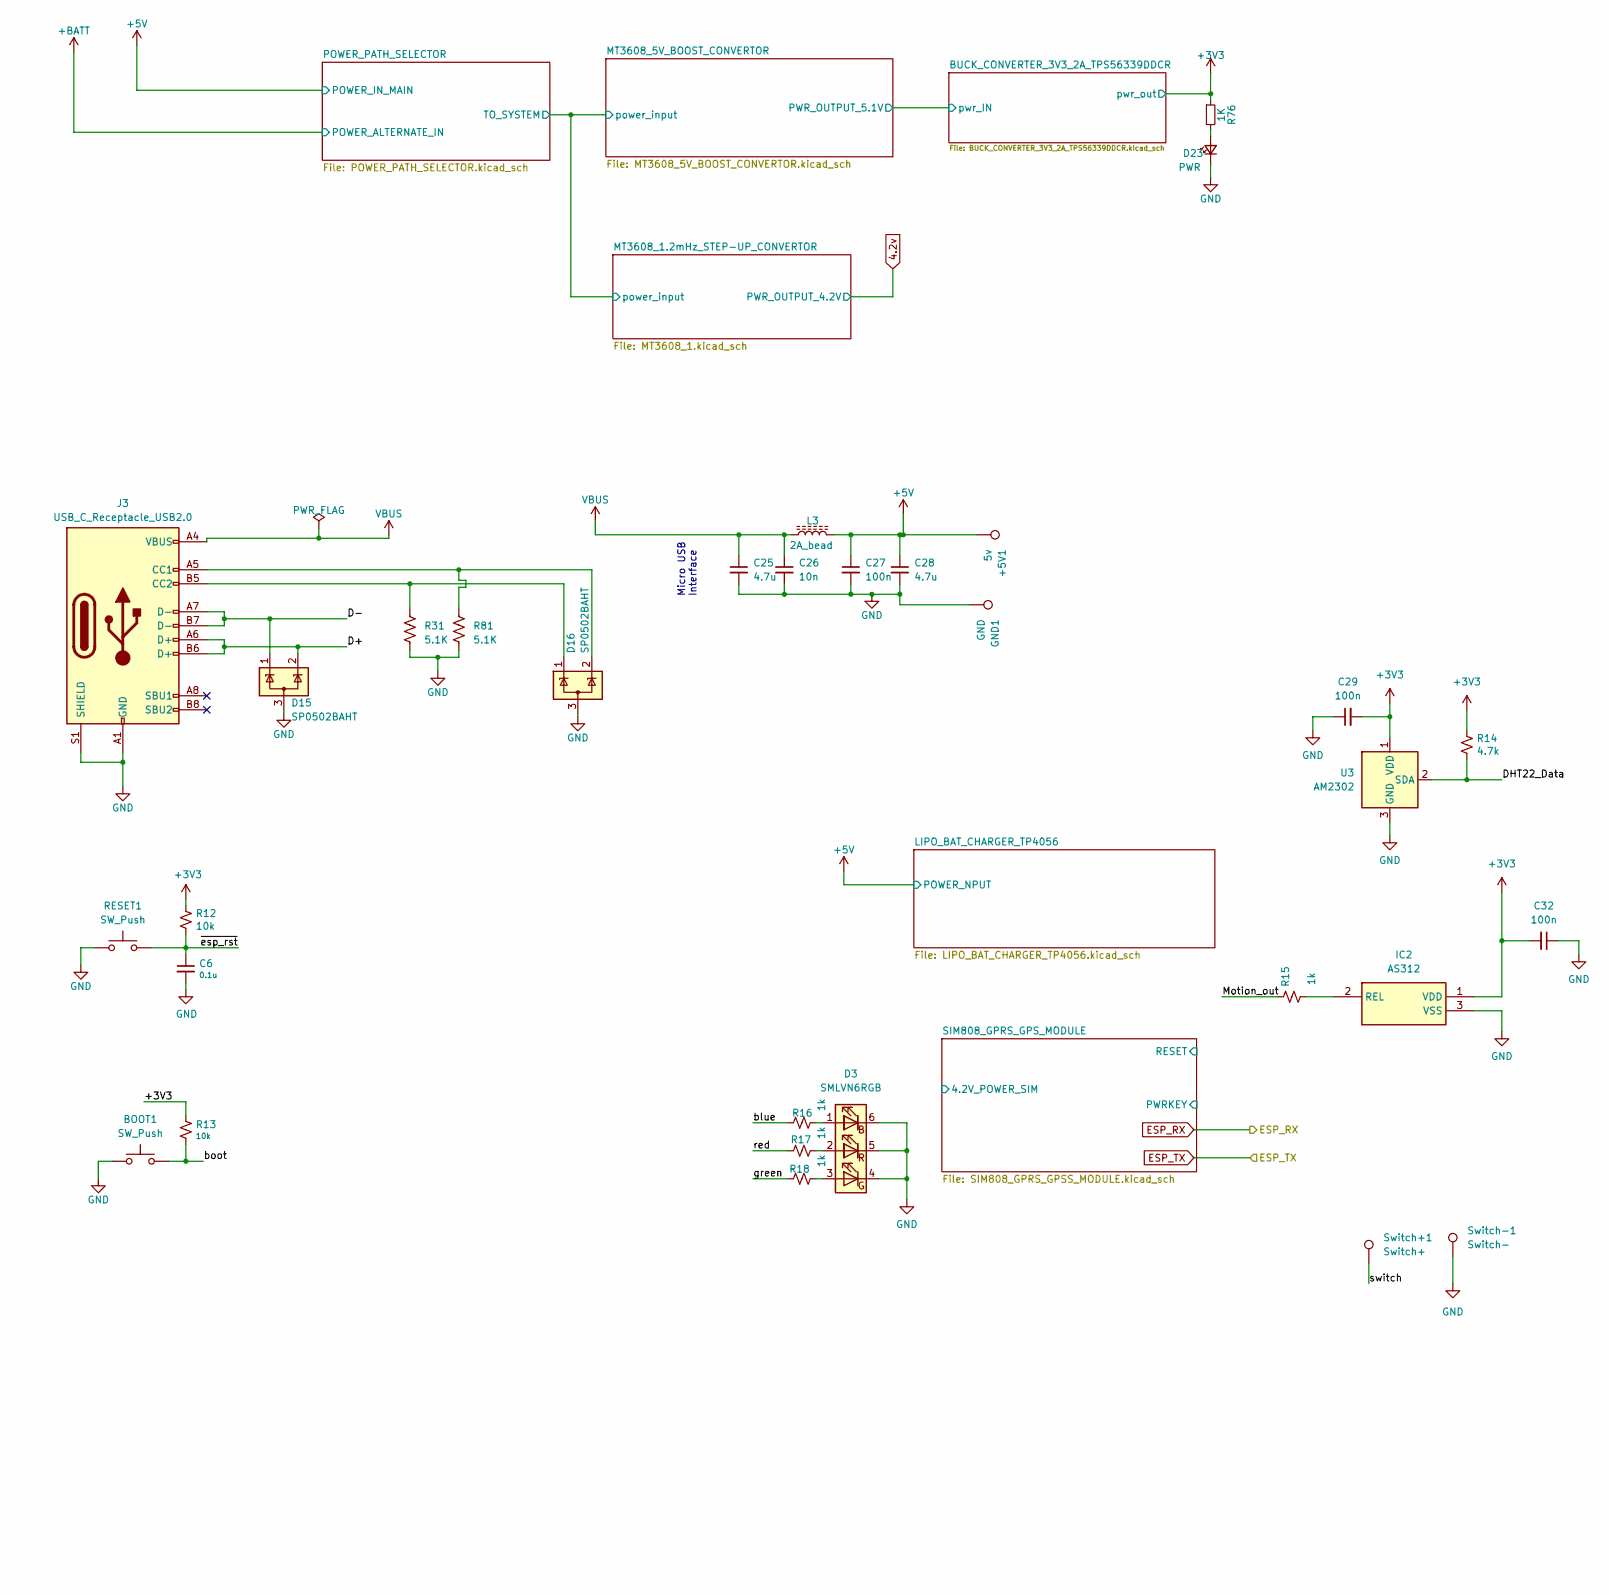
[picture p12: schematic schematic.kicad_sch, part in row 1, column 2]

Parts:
+5V1: 5v; TestPoint_Loop_D2.50mm_Drill1.85mm
BOOT1: SW_Push; SMT_4.2X3.2_
C6, C11: 0.1u; C_0402_1005Metric
C10: 10u; C_0402_1005Metric
C13: 22uF; C_0402_1005Metric
C14: 100nF; C_0402_1005Metric
C15, C16: 22pF; C_0402_1005Metric
C25, C28: 4.7u; C_0402_1005Metric_Pad0.74x0.62mm_HandSolder
C26: 10n; C_0402_1005Metric_Pad0.74x0.62mm_HandSolder
C27, C29, C32: 100n; C_0402_1005Metric_Pad0.74x0.62mm_HandSolder
D3: SMLVN6RGB; LED_ROHM_SMLVN6
D10, D11, D12: B5819W; D_SOD-123
D13: BAT54C; SOT-23
D15, D16: SP0502BAHT; SOT-23
D23: PWR; LED_0603_1608Metric
GND1: GND; TestPoint_Loop_D2.50mm_Drill1.85mm
IC2: AS312; Manufacturer_Part_Number AS312
J3: USB_C_Receptacle_USB2.0; USB_C_Receptacle_GCT_USB4105-xx-A_16P_TopMnt_Horizontal
L3: 2A_bead; L_0603_1608Metric
Q10, Q11: MMBT3904; SOT-23
R11, R12, R13, R19, R20, R21: 10k; R_0402_1005Metric
R14: 4.7k; R_0402_1005Metric
R15, R16, R17, R18: 1k; R_0402_1005Metric
R22: 220R; R_0402_1005Metric
R31, R81: 5.1K; R_0402_1005Metric
R76: 1K; R_0402_1005Metric
RESET1: SW_Push; SMT_4.2X3.2_
Switch+1: Switch+; TestPoint_Pad_D2.5mm
Switch-1: Switch-; TestPoint_Pad_D2.5mm
U3: AM2302; ASAIR_AM2302_P2.54mm_Vertical
U6: ESP32-WROOM-32
U8: CH340T(SSOP20W); SSOP-20_5.3x7.2mm_P0.65mm
Y1: 12MHz; Crystal_SMD_2520-4Pin_2.5x2.0mm

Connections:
+3V3: C10.1, C11.1, C29.2, C32.2, IC2.1 (VDD), R12.1, R13.1, R14.1, R76.1, U3.1 (VDD), U6.2 (VDD); also elsewhere on the board
+5V: +5V1.1, C13.1, C27.1, C28.1, L3.1, R11.1, U8.19 (VCC); also elsewhere on the board
/D+: D15.2 (K), J3.A6 (D+), J3.B6 (D+), U8.6 (UD+)
/D-: D15.1 (K), J3.A7 (D-), J3.B7 (D-), U8.7 (UD-)
/DHT22_Data: R14.2, U3.2 (SDA), U6.31 (IO19)
/IO2: D13.1, U6.24 (IO2)
/Motion_out: R15.1, U6.36 (IO22)
/blue: R16.1, U6.23 (IO15)
/boot: BOOT1.2, D13.2, R13.2, U6.25 (IO0)
/green: R18.1, U6.16 (IO13)
/red: R17.1, U6.14 (IO12)
/switch: Switch+1.1, U6.33 (IO21)
/~esp_rst: C6.1, D12.2 (A), R12.2, RESET1.2, U6.3 (EN)
ESP_RX: D10.2 (A), R19.2, U6.34 (RXD0/IO3)
ESP_TX: D11.1 (K), U6.35 (TXD0/IO1)
GND: BOOT1.1, C6.2, C10.2, C11.2, C13.2, C14.2, C15.2, C16.2, C25.2, C26.2, C27.2, C28.2, C29.1, C32.1, D3.4 (GK), D3.5 (RK), D3.6 (BK), D15.3 (A), D16.3 (A), D23.1 (K), GND1.1, IC2.3 (VSS), J3.A1 (GND), J3.A12 (GND), J3.B1 (GND), J3.B12 (GND), J3.S1 (SHIELD), R31.2, R81.2, RESET1.1, Switch-1.1, U3.3 (GND), U3.4 (GND), U6.1 (GND), U6.15 (GND), U6.38 (GND), U6.39 (GND), U8.8 (GND), Y1.2; also elsewhere on the board
IO4: U6.26 (IO4); also elsewhere on the board
IO25: U6.10 (IO25); also elsewhere on the board
IO26: U6.11 (IO26); also elsewhere on the board
IO27: U6.12 (IO27); also elsewhere on the board
IO32: U6.8 (IO32); also elsewhere on the board
IO33: U6.9 (IO33); also elsewhere on the board
IO34: U6.6 (IO34); also elsewhere on the board
unnamed: D3.1 (BA), R16.2
unnamed: D3.3 (GA), R18.2
unnamed: D3.2 (RA), R17.2
unnamed: D10.1 (K), U8.3 (TXD)
unnamed: D11.2 (A), R11.2, U8.4 (RXD)
unnamed: D12.1 (K), Q10.3 (C)
unnamed: D13.3, R22.1
unnamed: D23.2 (A), R76.2
unnamed: IC2.2 (REL), R15.2
unnamed: D16.2 (K), J3.A5 (CC1), R81.1
unnamed: D16.1 (K), J3.B5 (CC2), R31.1
unnamed: Q10.1 (B), R20.1
unnamed: Q11.1 (B), R21.1
unnamed: Q11.3 (C), R22.2
unnamed: C14.1, R19.1, U8.5 (V3)
unnamed: C15.1, U8.9 (XI), Y1.1
unnamed: C16.1, U8.10 (XO), Y1.3
VBUS: C25.1, C26.1, J3.A4 (VBUS), J3.A9 (VBUS), J3.B4 (VBUS), J3.B9 (VBUS), L3.2

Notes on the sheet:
Auto Reset Circuit
DTR RTS->EN IO0
Auto program
Micro USB Interface

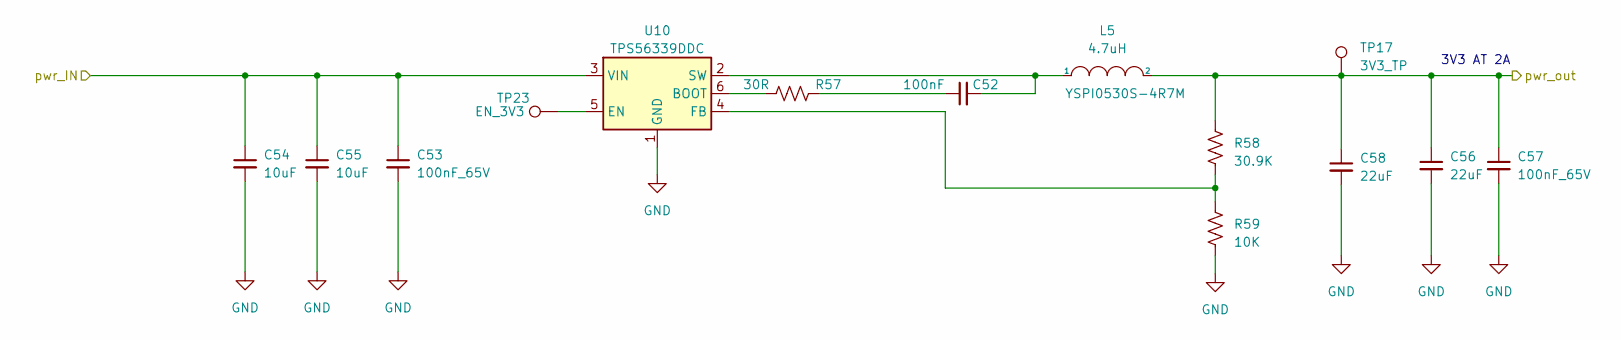
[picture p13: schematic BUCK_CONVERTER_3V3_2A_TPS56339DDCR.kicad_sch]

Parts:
C52: 100nF; C_0402_1005Metric
C53, C57: 100nF_65V; C_0402_1005Metric
C54, C55: 10uF; C_0805_2012Metric
C56, C58: 22uF; C_0603_1608Metric
L5: 4.7uH; L_Chilisin_BMRx00050512-B; MPN YSPI0530S-4R7M
R57: 30R; R_0402_1005Metric
R58: 30.9K; R_0402_1005Metric
R59: 10K; R_0402_1005Metric
TP17: 3V3_TP; TestPoint_Pad_D0.9mm
TP23: EN_3V3; TestPoint_Pad_D0.9mm
U10: TPS56339DDC; SOT-23-6

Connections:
+3V3: C56.1, C57.1, C58.1, L5.2, R58.1, TP17.1; also elsewhere on the board
/MT3608_5V_BOOST_CONVERTOR/5v: C53.1, C54.1, C55.1, U10.3 (VIN); also elsewhere on the board
GND: C53.2, C54.2, C55.2, C56.2, C57.2, C58.2, R59.2, U10.1 (GND); also elsewhere on the board
unnamed: C52.1, R57.2
unnamed: R57.1, U10.6 (BOOT)
unnamed: TP23.1, U10.5 (EN)
unnamed: R58.2, R59.1, U10.4 (FB)
unnamed: C52.2, L5.1, U10.2 (SW)

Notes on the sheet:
3V3 AT 2A

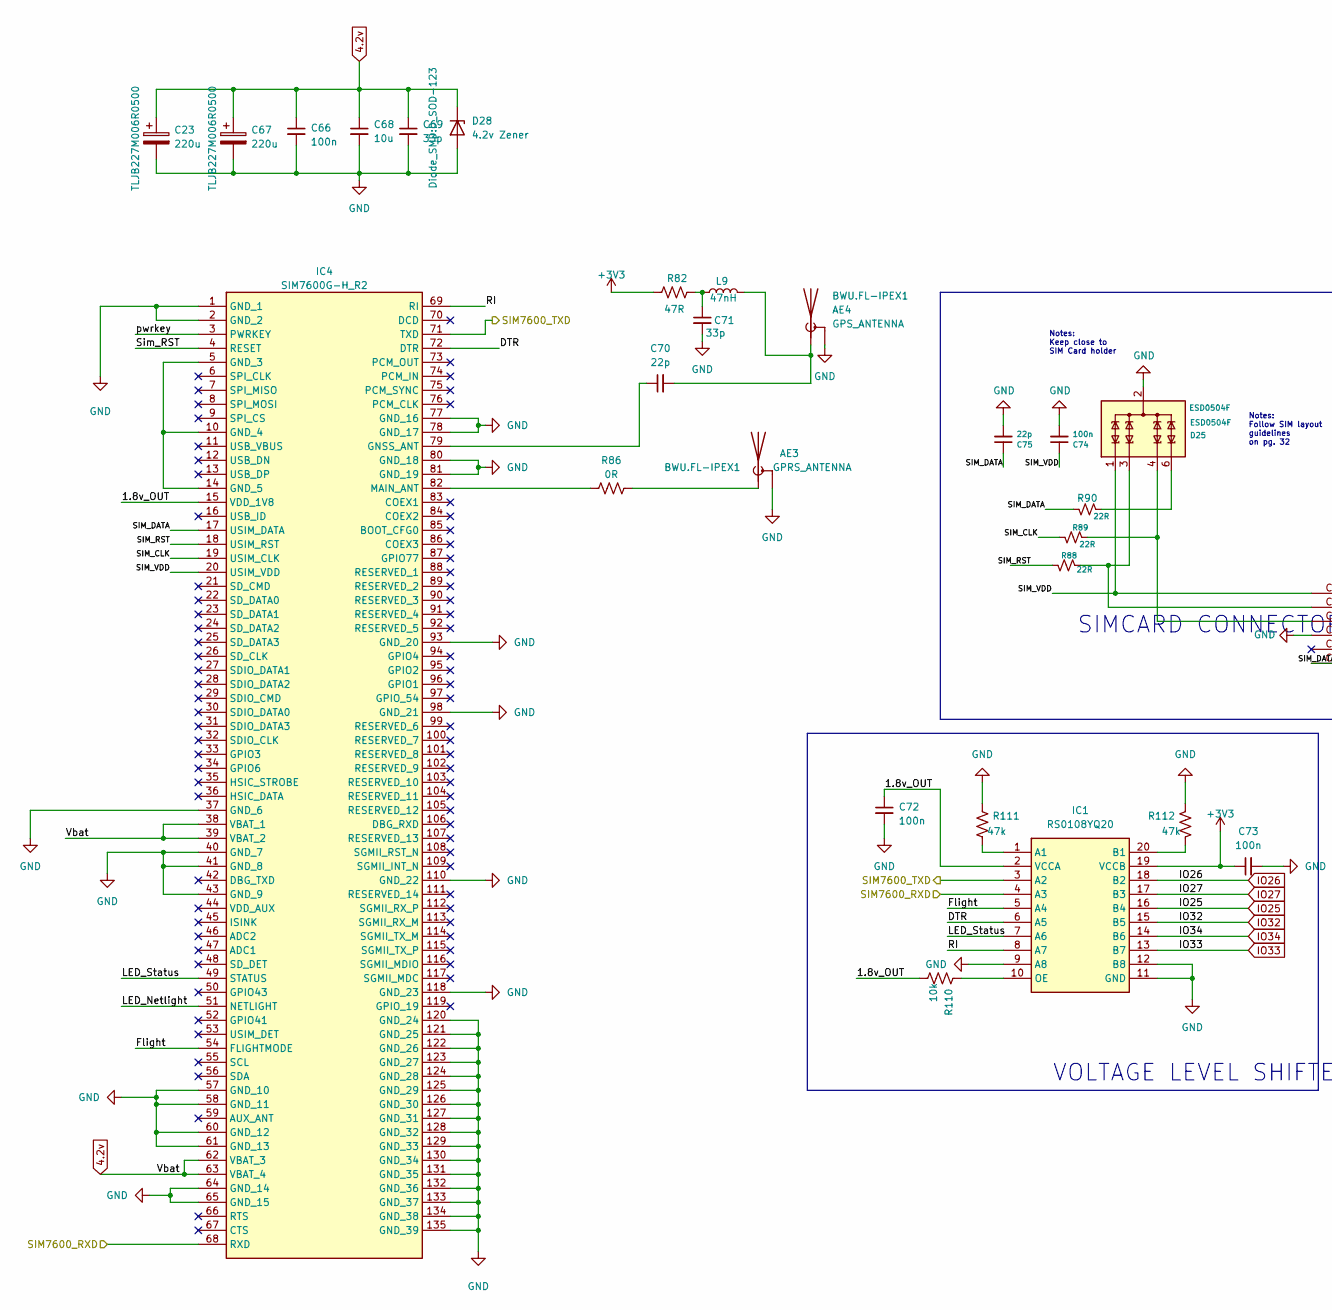
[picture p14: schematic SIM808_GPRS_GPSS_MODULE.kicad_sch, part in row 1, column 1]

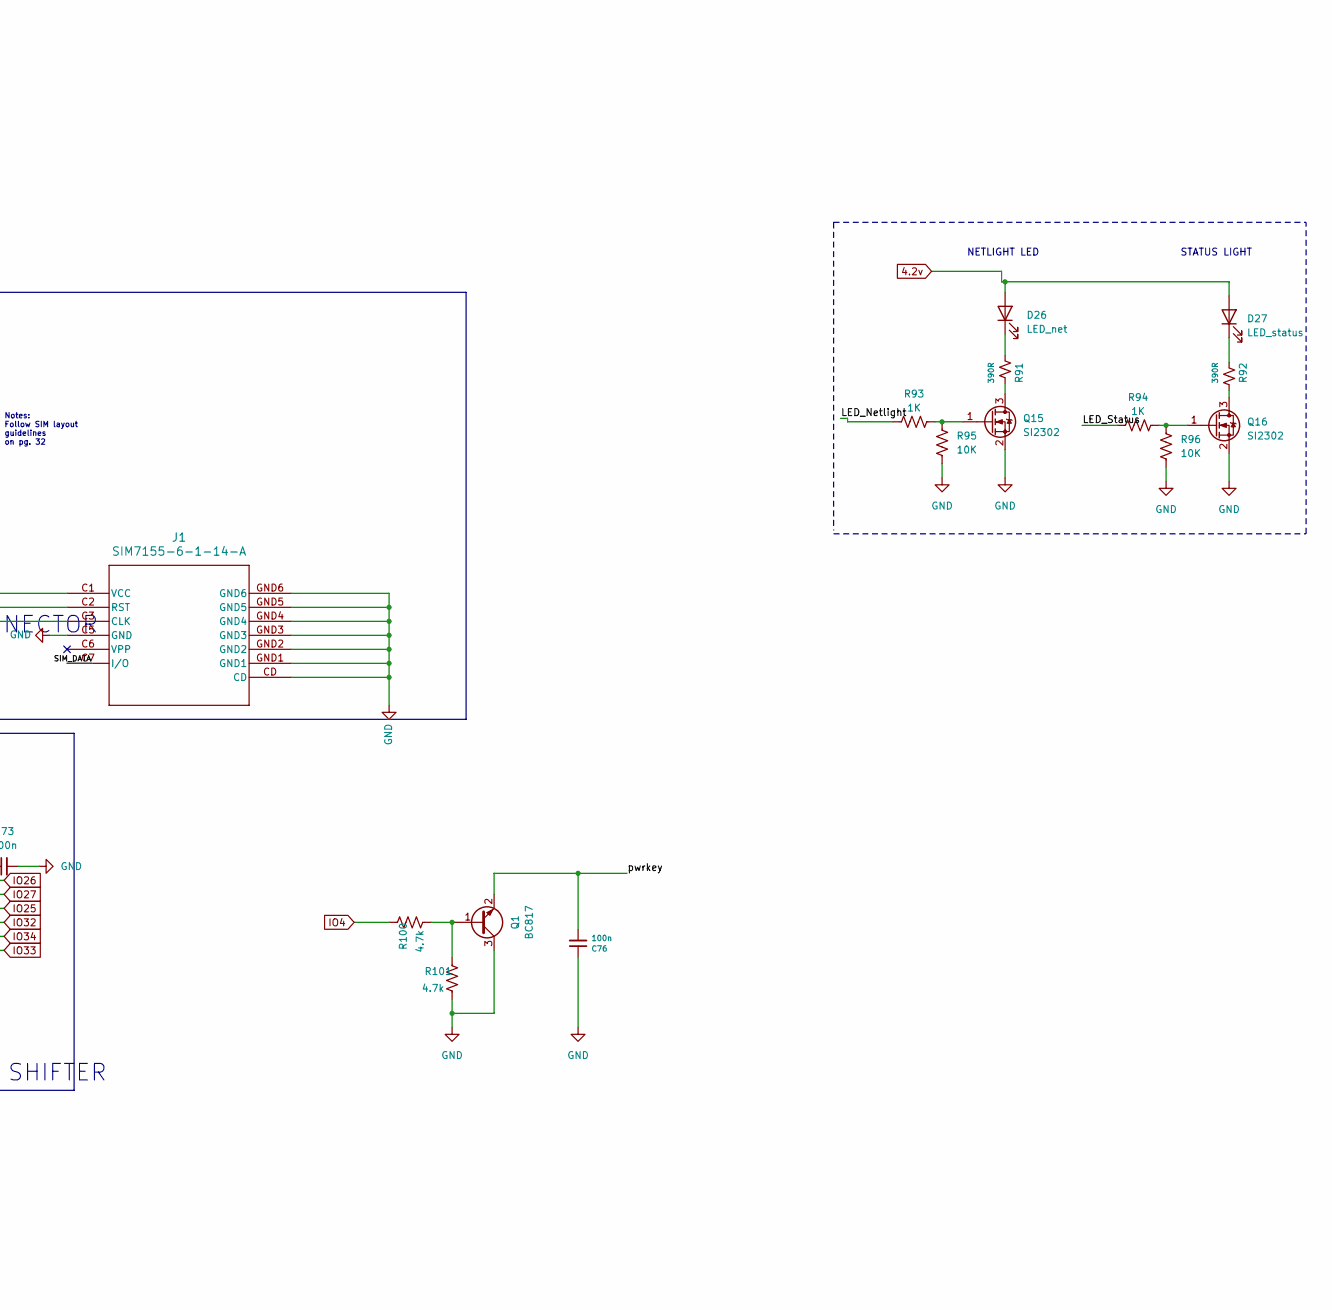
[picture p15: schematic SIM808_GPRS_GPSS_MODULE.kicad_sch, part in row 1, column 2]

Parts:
AE3: GPRS_ANTENNA; CONN_2337019-1_TEC; MPN BWU.FL-IPEX1
AE4: GPS_ANTENNA; CONN_2337019-1_TEC; MPN BWU.FL-IPEX1
C23, C67: 220u; CP_EIA-3528-21_Kemet-B; MPN TLJB227M006R0500
C66, C72, C73, C74, C76: 100n; C_0402_1005Metric
C68: 10u; C_0402_1005Metric
C69, C71: 33p; C_0402_1005Metric
C70, C75: 22p; C_0402_1005Metric
D25: ESD0504F; SOT-363_SC-70-6; MPN ESD0504F
D26: LED_net; LED_0603_1608Metric
D27: LED_status; LED_0603_1608Metric
D28: 4.2v Zener; D_SOD-123
IC1: RS0108YQ20; SOP65P640X120-20N; Manufacturer_Part_Number RS0108YQ20
IC4: SIM7600G-H_R2; SIM7600GHR2; Manufacturer_Part_Number SIM7600G-H R2
J1: SIM7155-6-1-14-A; SIM7155-6-1-14-A_GCT
L9: 47nH; L_0402_1005Metric
Q1: BC817; SOT-23
Q15, Q16: SI2302; SOT-23
R82: 47R; R_0402_1005Metric
R86: 0R; R_0402_1005Metric
R88, R89, R90: 22R; R_0402_1005Metric
R91, R92: 390R; R_0402_1005Metric
R93, R94: 1K; R_0402_1005Metric
R95, R96: 10K; R_0402_1005Metric
R100, R101: 4.7k; R_0402_1005Metric
R110: 10k; R_0402_1005Metric
R111, R112: 47k; R_0402_1005Metric

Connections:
4.2v: C23.1, C66.1, C67.1, C68.1, C69.1, D26.2 (A), D27.2 (A), D28.1 (K), IC4.38 (VBAT_1), IC4.39 (VBAT_2), IC4.62 (VBAT_3), IC4.63 (VBAT_4); also elsewhere on the board
+3V3: C73.1, IC1.19 (VCCB), R82.1; also elsewhere on the board
/SIM808_GPRS_GPS_MODULE/1.8v_OUT: C72.1, IC1.2 (VCCA), IC4.15 (VDD_1V8), R110.1; also elsewhere on the board
/SIM808_GPRS_GPS_MODULE/DTR: IC1.6 (A5), IC4.72 (DTR)
/SIM808_GPRS_GPS_MODULE/Flight: IC1.5 (A4), IC4.54 (FLIGHTMODE)
/SIM808_GPRS_GPS_MODULE/LED_Netlight: IC4.51 (NETLIGHT), R93.1
/SIM808_GPRS_GPS_MODULE/LED_Status: IC1.7 (A6), IC4.49 (STATUS), R94.1
/SIM808_GPRS_GPS_MODULE/RI: IC1.8 (A7), IC4.69 (RI)
/SIM808_GPRS_GPS_MODULE/SIM7600_RXD: IC1.4 (A3), IC4.68 (RXD)
/SIM808_GPRS_GPS_MODULE/SIM7600_TXD: IC1.3 (A2), IC4.71 (TXD)
/SIM808_GPRS_GPS_MODULE/SIM_CLK: IC4.19 (USIM_CLK), R89.2
/SIM808_GPRS_GPS_MODULE/SIM_DATA: C75.1, IC4.17 (USIM_DATA), J1.C7 (I/O), R90.2
/SIM808_GPRS_GPS_MODULE/SIM_RST: IC4.18 (USIM_RST), R88.2
/SIM808_GPRS_GPS_MODULE/SIM_VDD: C74.1, D25.1 (TVS1), IC4.20 (USIM_VDD), J1.C1 (VCC)
/SIM808_GPRS_GPS_MODULE/Sim_RST: IC4.4 (RESET)
/SIM808_GPRS_GPS_MODULE/pwrkey: C76.2, IC4.3 (PWRKEY), Q1.2 (E)
GND: AE3.2 (Shield), AE4.2 (Shield), C23.2, C66.2, C67.2, C68.2, C69.2, C71.2, C72.2, C73.2, C74.2, C75.2, C76.1, D25.2 (COM), D25.5 (COM), D28.2 (A), IC1.9 (A8), IC1.11 (GND), IC1.12 (B8), IC4.1 (GND_1), IC4.2 (GND_2), IC4.37 (GND_6), IC4.40 (GND_7), IC4.41 (GND_8), IC4.43 (GND_9), IC4.57 (GND_10), IC4.58 (GND_11), IC4.60 (GND_12), IC4.61 (GND_13), IC4.64 (GND_14), IC4.65 (GND_15), IC4.77 (GND_16), IC4.78 (GND_17), IC4.80 (GND_18), IC4.81 (GND_19), IC4.93 (GND_20), IC4.98 (GND_21), IC4.110 (GND_22), IC4.118 (GND_23), IC4.120 (GND_24), IC4.121 (GND_25), IC4.122 (GND_26), IC4.123 (GND_27), IC4.124 (GND_28), IC4.125 (GND_29), IC4.126 (GND_30), IC4.127 (GND_31), IC4.128 (GND_32), IC4.129 (GND_33), IC4.130 (GND_34), IC4.131 (GND_35), IC4.132 (GND_36), IC4.133 (GND_37), IC4.134 (GND_38), IC4.135 (GND_39), J1.C5 (GND), J1.CD, J1.GND1, J1.GND2, J1.GND3, J1.GND4, J1.GND5, J1.GND6, Q1.3 (C), Q15.2 (S), Q16.2 (S), R95.1, R96.1, R101.1, R111.2, R112.2; also elsewhere on the board
IO4: R100.2; also elsewhere on the board
IO25: IC1.16 (B4); also elsewhere on the board
IO26: IC1.18 (B2); also elsewhere on the board
IO27: IC1.17 (B3); also elsewhere on the board
IO32: IC1.15 (B5); also elsewhere on the board
IO33: IC1.13 (B7); also elsewhere on the board
IO34: IC1.14 (B6); also elsewhere on the board
unnamed: AE3.1 (A), R86.2
unnamed: AE4.1 (A), C70.2, L9.2
unnamed: C71.1, L9.1, R82.2
unnamed: D25.3 (TVS2), J1.C2 (RST), R88.1
unnamed: D25.4 (TVS3), J1.C3 (CLK), R89.1
unnamed: D25.6 (TVS4), R90.1
unnamed: D26.1 (K), R91.1
unnamed: D27.1 (K), R92.1
unnamed: IC1.1 (A1), R111.1
unnamed: IC1.20 (B1), R112.1
unnamed: IC1.10 (OE), R110.2
unnamed: IC4.5 (GND_3), IC4.10 (GND_4), IC4.14 (GND_5)
unnamed: C70.1, IC4.79 (GNSS_ANT)
unnamed: IC4.82 (MAIN_ANT), R86.1
unnamed 75: Q1.1 (B), R100.1, R101.2; also elsewhere on the board
unnamed: Q15.3 (D), R91.2
unnamed: Q15.1 (G), R93.2, R95.2
unnamed: Q16.3 (D), R92.2
unnamed: Q16.1 (G), R94.2, R96.2

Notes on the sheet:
VOLTAGE LEVEL SHIFTER
SIMCARD CONNECTOR
Notes: Follow SIM layout guidelines on pg. 32
Notes: Keep close to SIM Card holder
STATUS LIGHT
NETLIGHT LED

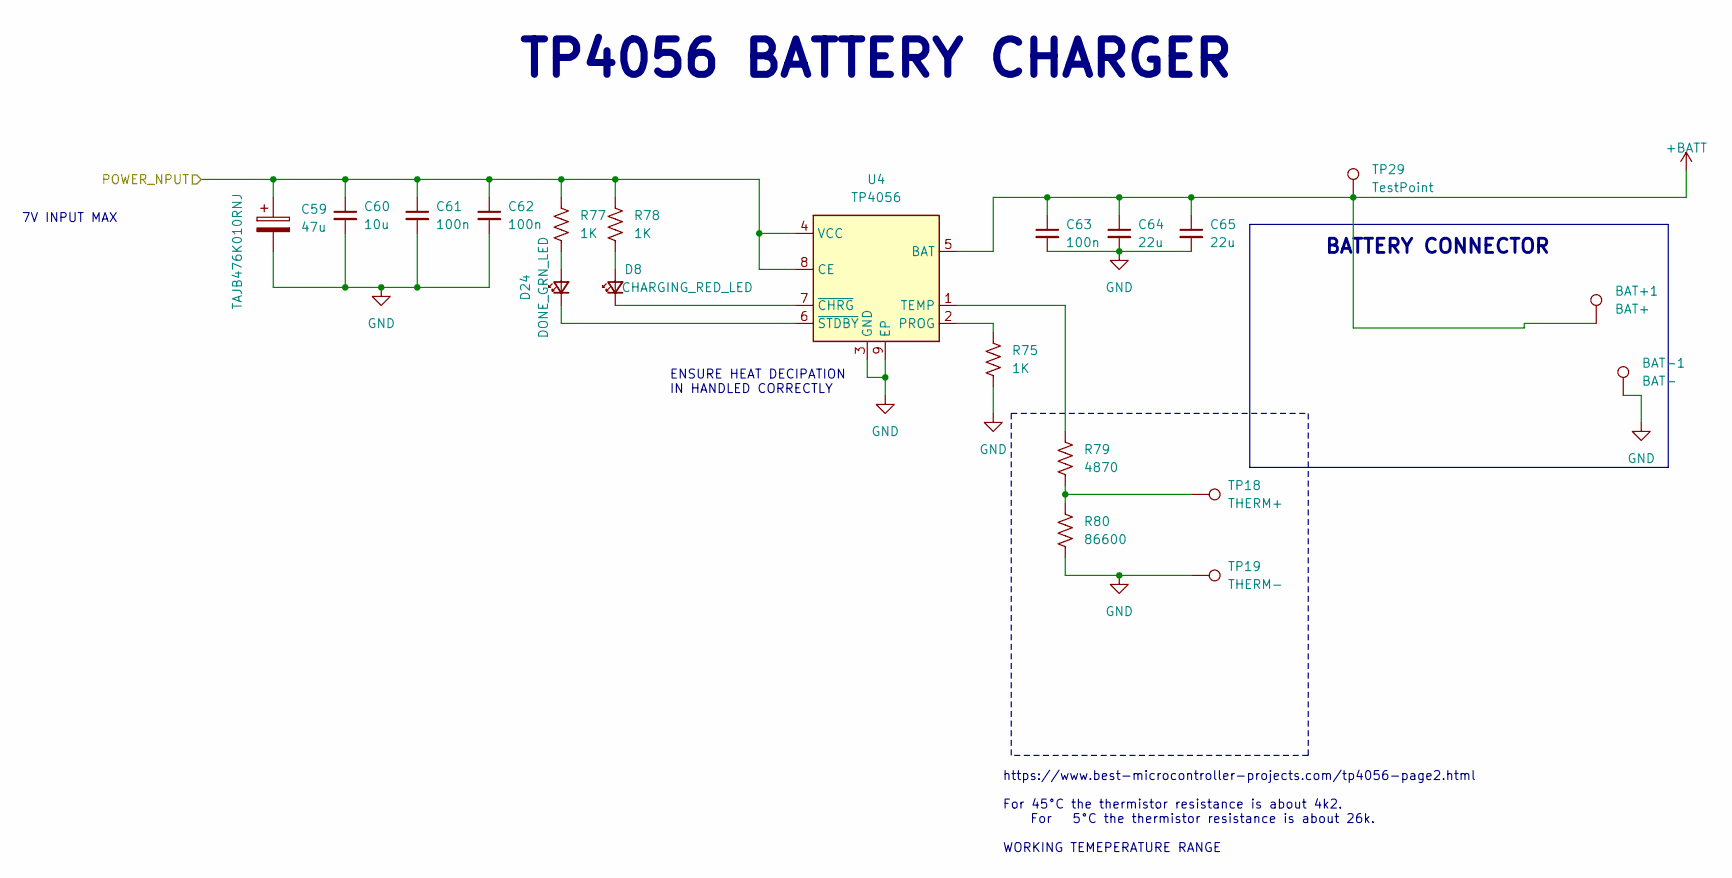
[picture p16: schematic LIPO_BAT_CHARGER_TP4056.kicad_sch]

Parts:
BAT+1: BAT+; TestPoint_Loop_D2.50mm_Drill1.85mm
BAT-1: BAT-; TestPoint_Loop_D2.50mm_Drill1.85mm
C59: 47u; CP_EIA-3528-21_Kemet-B; MPN TAJB476K010RNJ
C60: 10u; C_0603_1608Metric
C61: 100n; C_0603_1608Metric
C62, C63: 100n; C_0402_1005Metric
C64, C65: 22u; C_0402_1005Metric
D8: CHARGING_RED_LED; LED_0603_1608Metric
D24: DONE_GRN_LED; LED_0603_1608Metric
R75, R77, R78: 1K; R_0402_1005Metric
R79: 4870; R_0402_1005Metric
R80: 86600; R_0402_1005Metric
TP18: THERM+; TestPoint_Pad_D1.5mm
TP19: THERM-; TestPoint_Pad_D1.5mm
TP29: TestPoint; TestPoint_Pad_D0.9mm
U4: TP4056; SOIC127P600X175-9N

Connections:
+5V: C59.1, C60.1, C61.1, C62.1, R77.1, R78.1, U4.4 (VCC), U4.8 (CE); also elsewhere on the board
+BATT: BAT+1.1, C63.1, C64.1, C65.1, TP29.1, U4.5 (BAT); also elsewhere on the board
GND: BAT-1.1, C59.2, C60.2, C61.2, C62.2, C63.2, C64.2, C65.2, R75.2, R80.2, TP19.1, U4.3 (GND), U4.9 (EP); also elsewhere on the board
unnamed: D8.2 (A), R78.2
unnamed: D8.1 (K), U4.7 (~CHRG)
unnamed: D24.2 (A), R77.2
unnamed: D24.1 (K), U4.6 (~STDBY)
unnamed: R79.2, R80.1, TP18.1
unnamed: R75.1, U4.2 (PROG)
unnamed: R79.1, U4.1 (TEMP)

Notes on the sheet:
For 45°C the thermistor resistance is about 4k2. For 5°C the thermistor resistance is about 26k. WORKING TEMEPERATURE RANGE
TP4056 BATTERY CHARGER
7V INPUT MAX
https://www.best-microcontroller-projects.com/tp4056-page2.html
BATTERY CONNECTOR
ENSURE HEAT DECIPATION IN HANDLED CORRECTLY

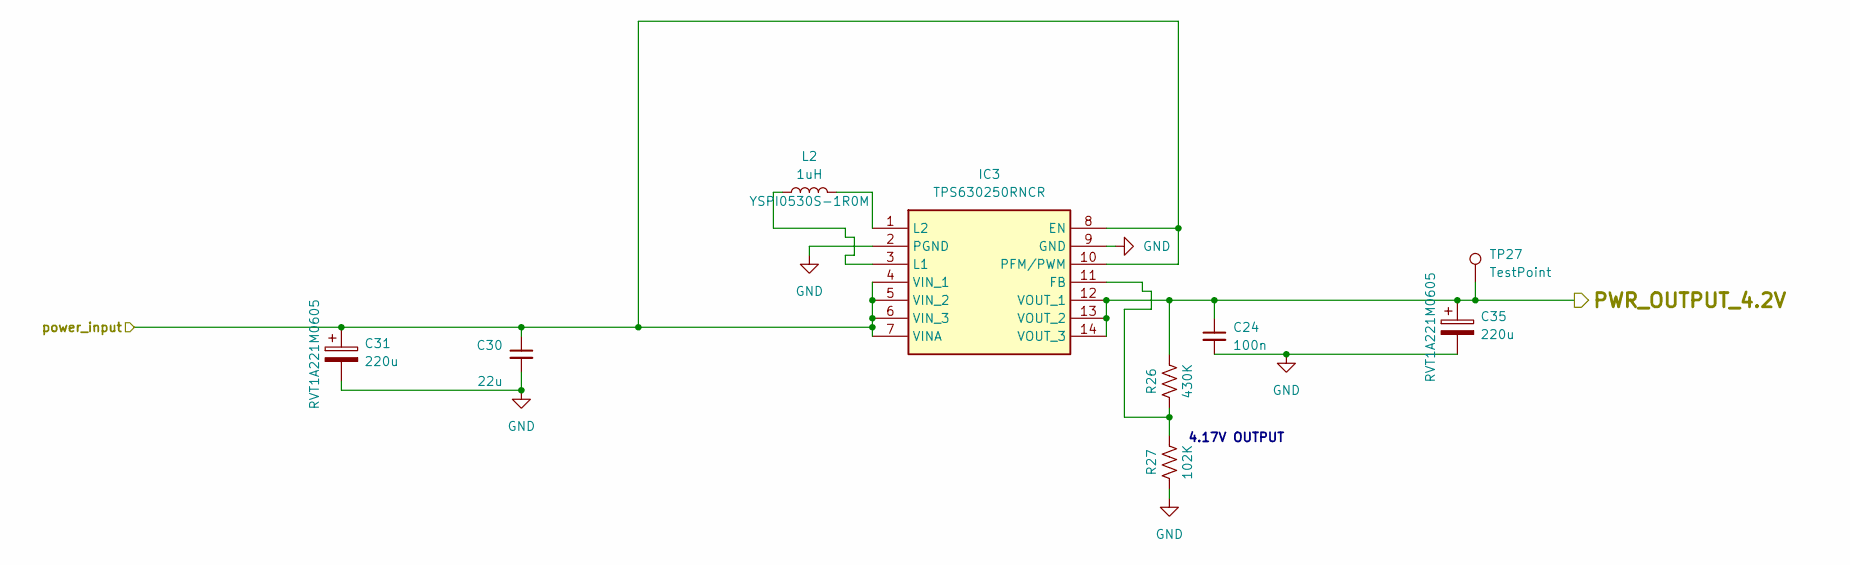
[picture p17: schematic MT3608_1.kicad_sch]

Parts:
C24: 100n; C_0402_1005Metric
C30: 22u; C_0402_1005Metric
C31, C35: 220u; CP_Elec_6.3x5.4; MPN RVT1A221M0605
IC3: TPS630250RNCR; Manufacturer_Part_Number TPS630250RNCR; Mouser Part Number 595-TPS630250RNCR
L2: 1uH; L_Chilisin_BMRx00050512-B; MPN YSPI0530S-1R0M
R26: 430K; R_0402_1005Metric
R27: 102K; R_0402_1005Metric
TP27: TestPoint; TestPoint_Pad_D0.9mm

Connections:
4.2v: C24.1, C35.1, IC3.12 (VOUT_1), IC3.13 (VOUT_2), IC3.14 (VOUT_3), R26.1, TP27.1; also elsewhere on the board
/MT3608_1.2mHz_STEP-UP_CONVERTOR/power_input: C30.1, C31.1, IC3.4 (VIN_1), IC3.5 (VIN_2), IC3.6 (VIN_3), IC3.7 (VINA), IC3.8 (EN), IC3.10 (PFM/PWM); also elsewhere on the board
GND: C24.2, C30.2, C31.2, C35.2, IC3.2 (PGND), IC3.9 (GND), R27.2; also elsewhere on the board
unnamed: IC3.11 (FB), R26.2, R27.1
unnamed: IC3.3 (L1), L2.1
unnamed: IC3.1 (L2), L2.2

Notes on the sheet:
4.17V OUTPUT

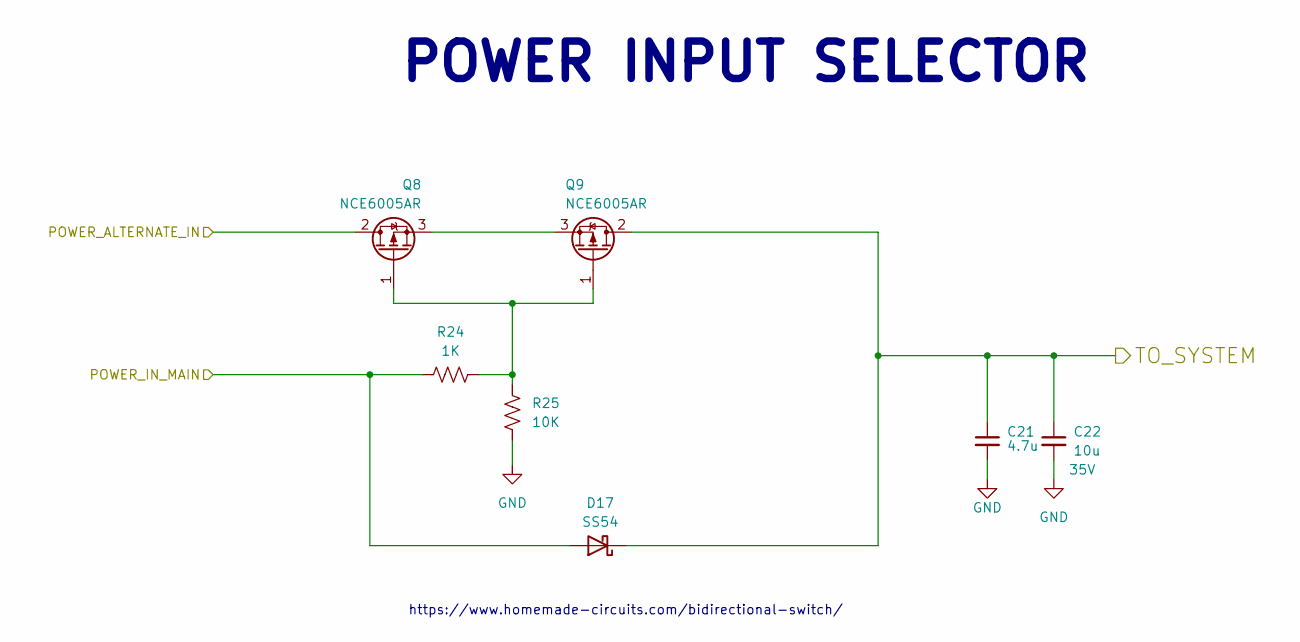
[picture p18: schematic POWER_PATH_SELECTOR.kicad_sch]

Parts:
C21: 4.7u; C_0603_1608Metric
C22: 10u; C_0603_1608Metric; VOLTAGE 35V
D17: SS54; D_SMA
Q8, Q9: NCE6005AR; SOT-223-3_TabPin2
R24: 1K; R_0603_1608Metric
R25: 10K; R_0603_1608Metric

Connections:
+5V: D17.2 (A), R24.1; also elsewhere on the board
+BATT: Q8.2 (D); also elsewhere on the board
/MT3608_1.2mHz_STEP-UP_CONVERTOR/power_input: C21.1, C22.1, D17.1 (K), Q9.2 (D); also elsewhere on the board
GND: C21.2, C22.2, R25.2; also elsewhere on the board
unnamed: Q8.1 (G), Q9.1 (G), R24.2, R25.1
unnamed: Q8.3 (S), Q9.3 (S)

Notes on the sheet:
POWER INPUT SELECTOR
https://www.homemade-circuits.com/bidirectional-switch/

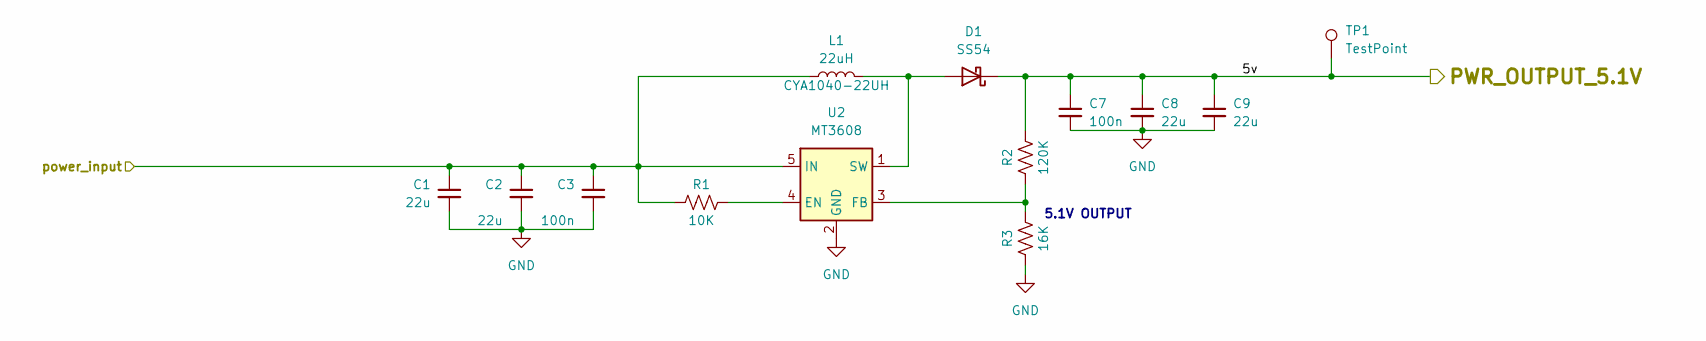
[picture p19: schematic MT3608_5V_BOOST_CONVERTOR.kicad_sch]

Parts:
C1, C2, C8, C9: 22u; C_0402_1005Metric
C3, C7: 100n; C_0402_1005Metric
D1: SS54; D_SMA
L1: 22uH; L_Chilisin_BMRG00101030; MPN CYA1040-22UH
R1: 10K; R_0402_1005Metric
R2: 120K; R_0402_1005Metric
R3: 16K; R_0402_1005Metric
TP1: TestPoint; TestPoint_Pad_D0.9mm
U2: MT3608; SOT-23-6

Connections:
/MT3608_1.2mHz_STEP-UP_CONVERTOR/power_input: C1.1, C2.1, C3.1, L1.1, R1.2, U2.5 (IN); also elsewhere on the board
/MT3608_5V_BOOST_CONVERTOR/5v: C7.1, C8.1, C9.1, D1.1 (K), R2.1, TP1.1; also elsewhere on the board
GND: C1.2, C2.2, C3.2, C7.2, C8.2, C9.2, R3.2, U2.2 (GND); also elsewhere on the board
unnamed: D1.2 (A), L1.2, U2.1 (SW)
unnamed: R1.1, U2.4 (EN)
unnamed: R2.2, R3.1, U2.3 (FB)

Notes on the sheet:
5.1V OUTPUT

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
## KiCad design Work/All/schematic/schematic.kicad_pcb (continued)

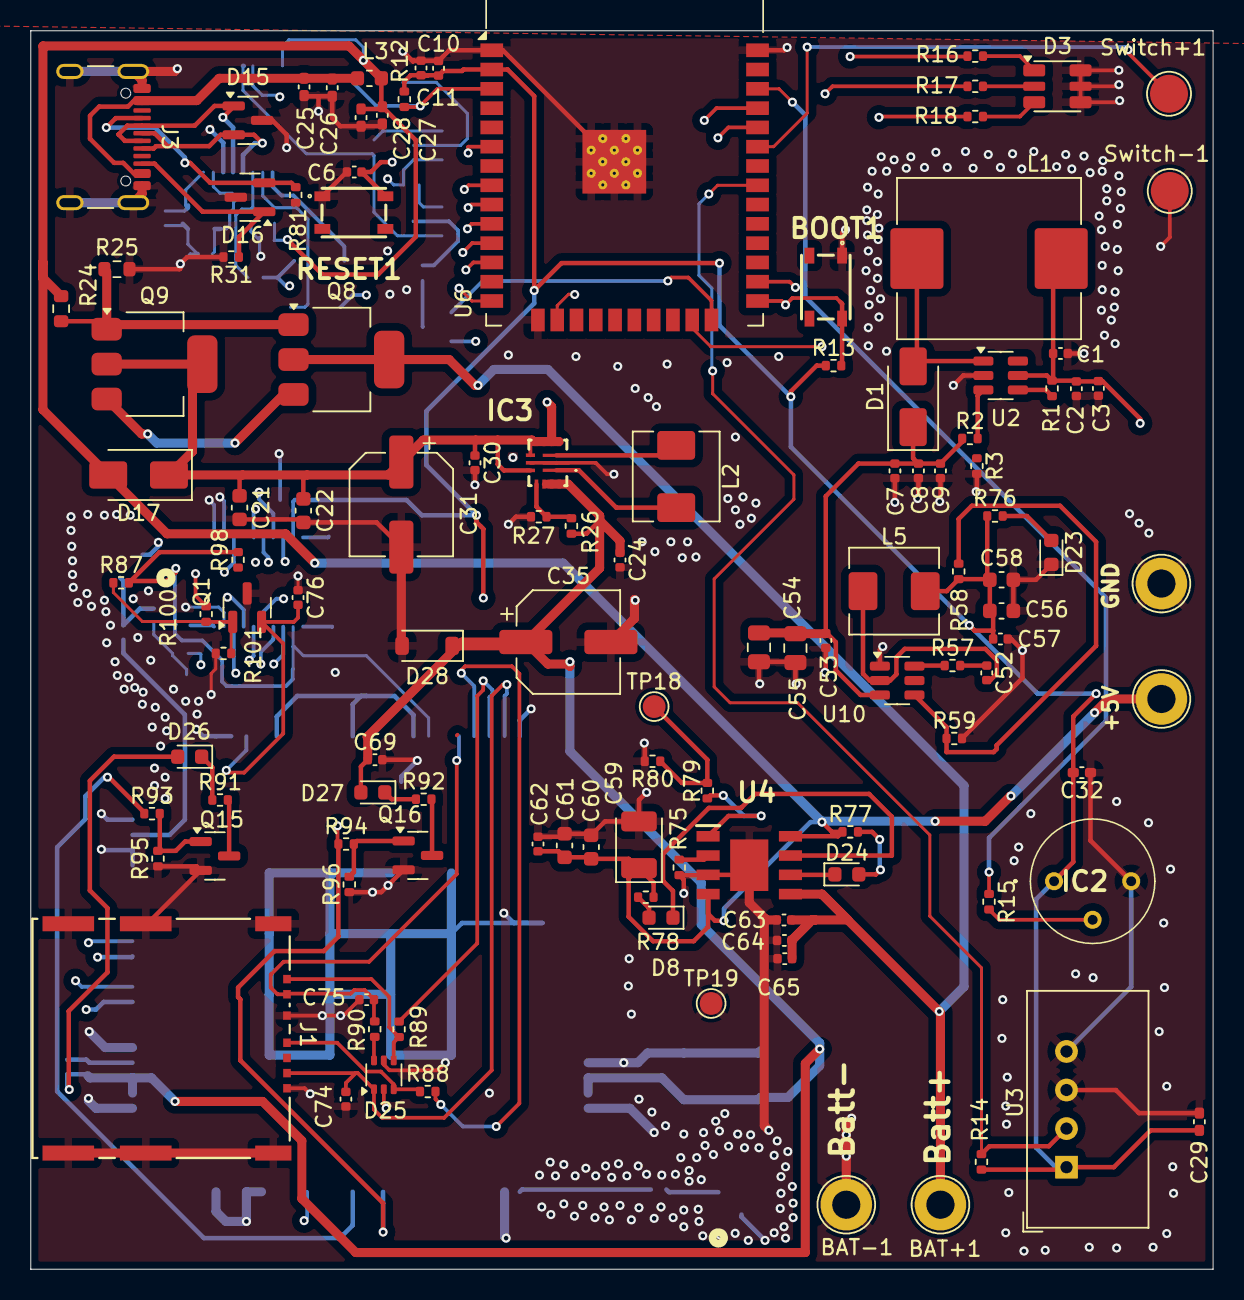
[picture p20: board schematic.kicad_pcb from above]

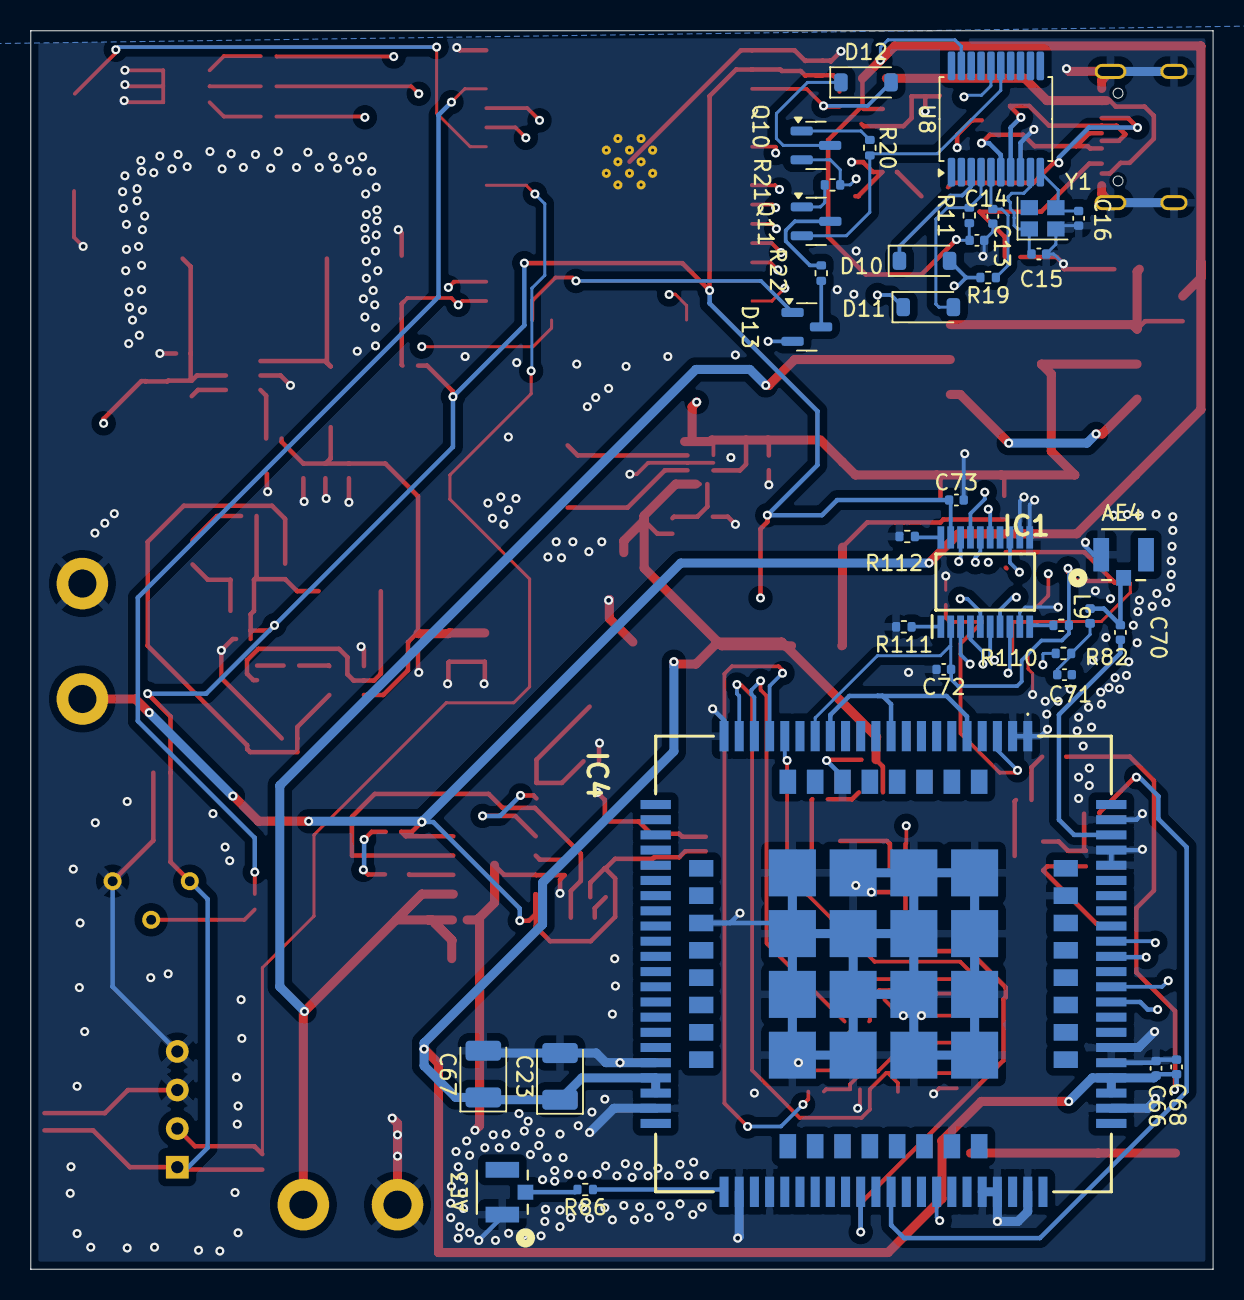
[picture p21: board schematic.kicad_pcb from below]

Board: 4 copper layers, 77.8 x 81.6 mm, 152 parts (35 on the bottom side), 98 nets.

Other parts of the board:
+5V: 5v; TestPoint_Loop_D2.50mm_Drill1.85mm
GND: GND; TestPoint_Loop_D2.50mm_Drill1.85mm
R87, R98: 4.7k; R_0402_1005Metric

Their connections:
+5V: +5V.1; also elsewhere on the board
/SIM808_GPRS_GPS_MODULE/1.8v_OUT: R87.2, R98.2; also elsewhere on the board
GND: GND.1; also elsewhere on the board
unnamed 75: R87.1; also elsewhere on the board

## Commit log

2026-08-25 shcematic complete
    [BUCK_CONVERTER_3V3_2A_TPS56339DDCR.kicad_sch, LIPO_BAT_CHARGER_TP4056.kicad_sch, MT3608_1.kicad_sch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]
2026-08-26 more Routing
    [BOM.csv, LIPO_BAT_CHARGER_TP4056.kicad_sch, SIM808_GPRS_GPSS_MODULE.kicad_sch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]
2026-08-27 changinge mcu and shift level
    [SIM808_GPRS_GPSS_MODULE.kicad_sch, schematic.kicad_sch]
2026-08-28 MORE Routing with Global names
    [BUCK_CONVERTER_3V3_2A_TPS56339DDCR.kicad_sch, LIPO_BAT_CHARGER_TP4056.kicad_sch, POWER_PATH_SELECTOR.kicad_sch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]
2026-08-28 Ground and power routing
    [schematic.kicad_pcb]
2026-09-01 Ground and power routing...
    [BOM.csv, bom.csv, designators.csv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]
